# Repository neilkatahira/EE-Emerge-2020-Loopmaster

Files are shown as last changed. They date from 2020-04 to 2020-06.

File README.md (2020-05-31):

# Loop Master

[Loopmaster](https://neilkatahira.github.io/EE-Emerge-2020-Loopmaster/) is a musical project created by a team of UC Davis [EE-Emerge](https://www.ece.ucdavis.edu/ieee/home/ee-emerge/) (EEC 105ABC) students. This project allows you to create your own musical melodies or riffs, regardless of skill level or knowledge. Three custom "instruments" interface together to output notes based on the user's selections.

## Table of Contents

1. [About the Project](#about-the-project)
2. [Project Status](#project-status)
3. [Getting Started](#getting-started)
    1. [Dependencies](#dependencies)
    1. [Building](#building)
4. [How to Get Help](#how-to-get-help)
5. [Further Reading](#further-reading)
6. [Authors](#authors)
7. [Acknowledgements](#acknowledgements)

# About the Project

Three instruments (Drumpad, Computer Vision, and Footpad) work with selections specified in a MATLAB GUI. A BeagleBone Black and a Bela Cape is utilized to process user inputs and output different notes.
The Drumpad works like a traditional MIDI pad, where each of the twelve buttons are mapped to notes that relate to a selection of instruments. The Computer Vision maps different notes to select areas in a camera's view and outputs sound when a trigger is visible. The Footpad takes input from a user's feet and manipulates the sounds created by the Camera Vision and Drumpad.

# Project Status

Final assembly and code refinement.

# Getting Started

This repository can be downloaded [here](https://github.com/neilkatahira/EE-Emerge-2020-Loopmaster/archive/master.zip), or cloned by:
```
git clone https://github.com/neilkatahira/EE-Emerge-2020-Loopmaster
```

## Dependencies

#### Software
[Energia](https://energia.nu/)  
Energia is required for the Drumpad and Footpad to compile and run the .ino files.

[OpenMV IDE](https://openmv.io/pages/download)  
The OpenMV IDE is used for all of the programming of the H7 Camera.

[PureData](https://github.com/BelaPlatform/Bela/wiki/Getting-started-with-Bela)  
The Bela IDE is used for the majority of the workflow for the Beaglebone + Bela.

#### Hardware & Model Creation
[Altium](https://www.altium.com/) was used for most PCB creation.  
[Eagle](https://www.autodesk.com/products/eagle/overview) was used to make the CameraPCB.  
[Fusion 360](https://www.autodesk.com/products/fusion-360/overview) was used for the creation of enclosures and other mechanical files.  
[Cura](https://ultimaker.com/software/ultimaker-cura) was used as our main slicer for 3D printing. The UC Davis ESDC's Ultimaker's and personal Ender 3 Pro's were used for fabrication.  

## Building

PCB and enclosure files will be located in their respective subdirectories. These were fabricated either with a 3D printer, a laser cutter, or table saw.

Software for the instruments will have to be compiled and loaded into their respective MCU's either in the Puredata IDE or Energia.

# How to Get Help

You can request any changes by making a [pull request](https://github.com/neilkatahira/EE-Emerge-2020-Loopmaster/pulls) or opening an issue.

# Further Reading
* [Airdrum](https://hackaday.com/2019/11/15/finally-your-air-drumming-has-an-outlet/)
* [Foot Piano](https://www.instructables.com/id/Build-a-Big-Piano/)

# Authors

* [Benjamin Moore](https://github.com/mooreben34)
* [Conrad Rowling](https://github.com/Conrad-Rowling)
* [Neil Katahira](https://github.com/neilkatahira)
* [Jocelyn Park](https://github.com/spectivePer)
* [Isabelle Asistin](https://github.com/ijasistin)
* [Varsha Senthil](https://github.com/varshaaaaa)
* [Tyler Kelley](https://github.com/tfkelley)
* [Ryan Ma](https://github.com/RyanMa1)
* [Devon Liu](https://github.com/dvnliu)
* [Sean Alling](https://www.ece.ucdavis.edu/blog/alling-sean/)
* [Professor Andre Knoesen](https://faculty.engineering.ucdavis.edu/knoesen/)

# Acknowledgments

Thanks to Texas Instruments for sponsoring EE-Emerge, along with Sean Alling and Dr. Andre Knoesen. We would not have gotten this far without their help and support.

Huge shout out to Alessandro Verdiesen and Luuk van Kuijk with the original idea and inspiration of the [Airdrum](https://hackaday.com/2019/11/15/finally-your-air-drumming-has-an-outlet/) and the whole project.

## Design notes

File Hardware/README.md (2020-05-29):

# Hardware Designs

Our system was fairly robust, and we needed quite a few board to complete it. The backbone of our hardware was based on the following boards:

[BeagleBoneBlack](https://beagleboard.org/black)  
[Bela Cape](https://beagleboard.org/p/112305/bela-low-latency-audio-sensor-cape-for-pocketbeagle-1615e0)  
[MSP430G2 LaunchPad](http://www.ti.com/tool/MSP-EXP430G2)  
[OpenMV H7](https://openmv.io/products/openmv-cam-h7)  
Capsense Buttons
Power Supply
Batteries

Once we proved functionality, we designed our own circuitboards to improve the connections as well as size parameters of the pre-fabricated boards.

## Table of Contents

1. [Board Selection](#board-selection)  
   - [BeagleBoneBlack/BelaCape](#beagleboneblack/belaCape)  
   - [OpenMV H7](#openMv-h7)  
   - [MSP430](#msp430)  
   - [Xbee Module](#xbee-module)  
   - [Miscellaneous](#miscellaneous)  
2. [Custom Boards](#custom-boards)  
   - [Beagle Cape Cape](#beagle-cape-cape)  
   - [Drumpad/Keypad](#drumpad/keyboard)  
   - [Camera Cape](#camer-cape)  
   - [Button Wiring Harness](#button-wiring-harness)  
    
## Board Selection

### BeagleBoneBlack/BelaCape  
The base of project was creating music, which meant making quality sounds at a responsive rate. This meant we needed low latency, as low as we could get it within budget! We built our system around the [BeagleBoneBlack](https://beagleboard.org/black) and [Bela Cape](https://beagleboard.org/p/112305/bela-low-latency-audio-sensor-cape-for-pocketbeagle-1615e0) which would combined process the input of instruments and output fast and quality sound.

### OpenMV H7  
We chose the OpenMV H7 because it is a relatively cheap, low power camera, that has loads of documentation and is very easy to work with. It has more than enough processing power to accomplish our tasks, as well as an IDE that uses python. 

### MSP430  
We chose to use these boards because everyone on our team had experience working with them, they are easy to use, and use an IDE that is almost identical to the Arduino IDE. They were also provided to us in launchboard form by [Texas Instruments](http://www.ti.com/) which vastly accelerated the project developement phase. - BIG THANKS! 

### Xbee Module  
The Xbee module was a final implementation on the project to provide wireless communication. These modules are incredibly easy to use, and are very small. They are an excellent choice to provide wireless serial communication.

### Miscellaneous  
Power Supply, Batteries, Voltage Regulators and Capsense tech

## Custom Boards  
We used several Integrated Processors in the development of our project. In most cases we used development boards, jumperwires and breadboards which allowed easy connections to test functionality. We started with but the finished project was something professional, so we designed our own boards to house the integrated chips we were programming ([MSP430](http://www.ti.com/microcontrollers/msp430-ultra-low-power-mcus/overview.html)'s) as well as capes for the pre-fabricated boards we were using ([OpenMV H7](https://openmv.io/products/openmv-cam-h7) and [BeagleBoneBlack](https://beagleboard.org/black)/[Bela Cape](https://beagleboard.org/p/112305/bela-low-latency-audio-sensor-cape-for-pocketbeagle-1615e0)).This allowed us to create more stable connection points, remove unnecessary functions, and create room for new functions (Xbee wireless Communication).

### Beagle Cape Cape  
We designed a board that would connect to the breakout pins of the BeagleBoneBlack. It replaced the GPIO pinnouts with screw terminal connections for the required Serial ports and 3.3V rail. It also laid a footprint for a permanent addition of an Xbee module.

### Drumpad/Keypad  
We developed one board that would function for both the Drumpad as well as the foot keyboard. It housed a MSP430 and provided ample room for the GPIO pins that were needed in instrument function.(MORE DETAILS) THe board replaced the GPIO pin out with screw terminals for better permanent connections. The board was also made with a footprint for an Xbee module to be soldered on.

### Camera Cape  
The most simple board we designed for the OpenMV camera module, it took the pinouts we needed from the development board and implemented screw terminals for better permanent connections.

### Drumpad Wiring Harness  
We designed a board that simplified the wiring harness for 12 capacitive sense buttons. Each button required an op-amp to forward the button data as well as provide power to LEDs. We developed a board that made this complex wiring array compact and easy to trouble shoot. This allowed us to reduce the overall size requirements of the Drumpad Enclosure as well as reducing EM noise within the enclosure.

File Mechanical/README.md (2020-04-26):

# Hub
We designed a centralized hub to house everything from a powersupply to our finished boards. Changes had to be made from laser cutting to 3D printing, so the model had to be broken up into printable pieces.

# Camera
To mount the OpenMV H7 camera we used a STL file provided by OpenMV [here](https://openmv.io/collections/products/products/openmv-cam-h7-case) and modified it into a vertical mount with a ball and socket adjustment.

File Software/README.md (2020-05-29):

# Software  
Multiple Programming Languages and Development environments were used to design instrument logic as well as handle audio processing.

## Pure Data  
Pure Data is an open source programming language with a focus on multimedia applications. It was used for the Loopmaster's core audio backend since Pure Data has core native support on the Bela Cape Board. More information about the project's main .pd module and its abstractions can be found in its subdirectory.

## Camera  
The camera code is written in python using the OpenMV IDE. Its used for object detection and tracking, specifically looking for an LED in a grayscale image and pinging when that LED enters regions we've determined to output notes.

## GUI  
The GUI was created with MATLAB's App Designer. It utilizes UART to send data to an Arduino Uno, which then is sent and processed by the Beaglebone + Bela with the help of PureData.

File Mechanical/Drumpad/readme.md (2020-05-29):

# Drumpad  
The entire enclosure is 3D printed using an Ender 3 Pro using PLA using 0.2mm layer height. To improve printing time, a larger layer height with a larger nozzle will help.  

## Assembly  
Drumpad Base + Walls.stl and Drumpad Top.stl go together to make a single box. Inside are standoffs for the Drumpad LED pcb, and space for the actual brains of the instrument. Sensor Enclosure.stl is a model of for a Capsense sensor, just in case you want to adapt it to another design. Drumpad PCB plate .stl is a simple plate that screws underneath the Drumpad LED pcb with M3 screws and nuts if not using the original enclosure.

## Notes  
Supports for a hole in the Drumpad Base + Walls.stl may or may not be required depending on the capabilities of your printing solution. Print with a brim if issues such as corners warping occur. Scaling may break how everything comes together, so if your print bed is not big enough, slice in half and put together with superglue or by other means.

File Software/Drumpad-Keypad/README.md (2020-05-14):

# Drumpad/Keypad Code
The code for the drumpad/keypad was developed in the energia IDE and is fairly straightforward: It polls the GPIO pins for a change of state, either being pressed or released. The code reads the status of each pin and compares it to a flag that describes the state it was previously in. When pressed a PRESS flag is set, and is not removed until the digital value of the pin falls below the boolean value of the flag. Then the process is repeated. Each pin sends a unique 8 bit char to through UART to the bela telling it which key was pressed/released.

# Keypad Code
The Keyboard code is written in C and programmed on the MSP430. Each of the keys is connected to a different pin on the MSP430. When a key is pressed, the two boards with copper tape make contact with each other, and the corresponding pin on the MSP is read, and an output is sent through UART as a single character. We programmed each key to output a different character to identify which key was being pressed. This is looped continuously and the Bela reads the characters sent to output the corresponding sounds.

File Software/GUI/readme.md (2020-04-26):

## MATLAB GUI
Found in the MATLAB folder is a MATLAB App Designer GUI with an exported .m file for full modification.

## Arduino
In the Arduino folder, there resides a file for taking serial data from MATLAB, parsing and sending with UART. There is also a second optional Arduino file for sniffing what is sent with MATLAB.

## Setup
1. Connect Arduino to computer by USB.
2. Connect Arduino TX -> Beaglebone BELA RX. Alternatively, connect to another Arduino UNO with TEST_serialReceive.ino. Connect to ground to establish physical UART.
    * If using second Arduino UNO, load code in TEST_serialReceive.ino with GND disconnected. Then, reconnect GND.
3. Open UART_GUI.ino in Arduino IDE. Check COM ports and upload to board.
4. Open LoopMasterApp.mlapp. Check COM port and baudrate in line 45. Change accordingly and run. Make sure connections are secure and data is sent/received.

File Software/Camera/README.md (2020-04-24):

# OpenMV Code
The software for tracking our camera instrument was developed in OpenMVide. This was a really straightforward IDE with tons of community activity. It had plenty of options to improve the code using computer learning algorithms and object identification. We tested a variety of different ways to track an object and found that using simple algorithms lead to in accurate readings, and using complex algorithms - TensorFLow or other computer training- to identify and track an object created too much of a delay. From those preliminary tests, we decided to simplify the object instead. We tracked an LED in grayscale and searched for areas in which the pixel value was white < [253]. To do this we used an algorithm provided in the openmv micropython libray call findblobs() you pass it threshold values to define what kind of blob and the size requirements. It will find all the blobs that meet that criteria, then we searched through those blobs to see if the center of any of those blobs fit inside certain areas of the screen (each corner). If a blob is in a corner we send the bela a code to play a note designated by that corner.

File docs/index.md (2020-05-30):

# LoopMaster

[LoopMaster](https://neilkatahira.github.io/EE-Emerge-2020-Loopmaster/) is a musical project created by a team of UC Davis [EE-Emerge](https://www.ece.ucdavis.edu/ieee/home/ee-emerge/) (EEC 105ABC) students. This project allows you to create your own musical melodies or riffs, regardless of skill level or knowledge. Three custom "instruments" interface together to output notes, chords, and audio manipulations based on the user's selections.  

{%include youtubePlayer.html id="1H5Hb9ecIn0"%}  

# About the Project:
The goal of this project was to create a functional music creation tool, and demonstrate various input methods. We wanted to make something that was easy for beginners to pick up and make something that sounds nice, but also create an enjoyable experience for someone more serious.<br/>

However there are many factors that can detract from musical creation, particulary poor sound quality and latency. To ensure that the music we were making was responsive and sounded good, we designed our project around the [Bela](https://shop.bela.io/products/bela-starter-kit):

{%include youtubePlayer.html id="Os2ljj1cIog"%}

We used it in conjunction with a [BeagleBone Black](https://beagleboard.org/black) to process incoming signals, and respond with fast - quality sound. <br/>

The next step was creating a way to get user input; we thought of a couple very creative was to use technologies like [Capsense Buttons](https://en.wikipedia.org/wiki/Capacitive_sensing) and an easy to use [Computer Vision Module](https://openmv.io/). We built our own Circuit Boards to house MicroControllers that would process our user input, and convert it to UART. We chose the [MSP430G2553](https://www.ti.com/product/MSP430G2553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) for our microcontroller because [TI](https://www.ti.com/) sponsored our course, and the associated [Launchpad](http://www.ti.com/tool/MSP-EXP430G2) drastically increased our software development time. <br/>

Then we decided to take the project wireless! using a straightforward network of [XBee](https://www.adafruit.com/product/964) modules we were able to send multiple UART messages in unison, and create a modular sleek look to the system.

Our final signal flow chart ended up like this:

<p align="center">
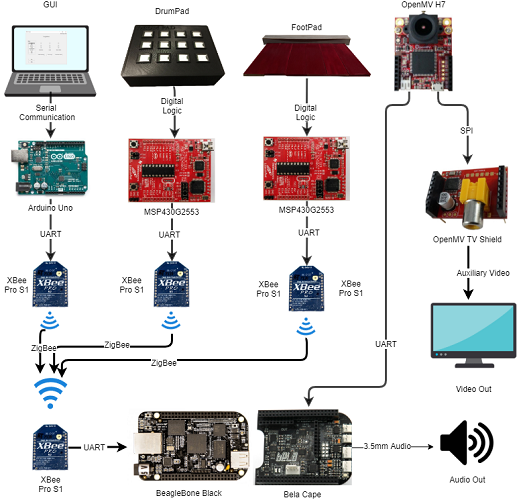
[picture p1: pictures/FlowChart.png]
  
</p>

<video>

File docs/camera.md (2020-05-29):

# Camera

## Hardware  
We chose the OpenMV H7 because it is an affordable, low power camera that is well documented and easy to work with. It has more than enough processing power to accomplish our tasks, as well as an integrated Python based IDE. Using Python allowed us to take advantage of open source libraries, which simplified the learning curve of image processing algorithms.

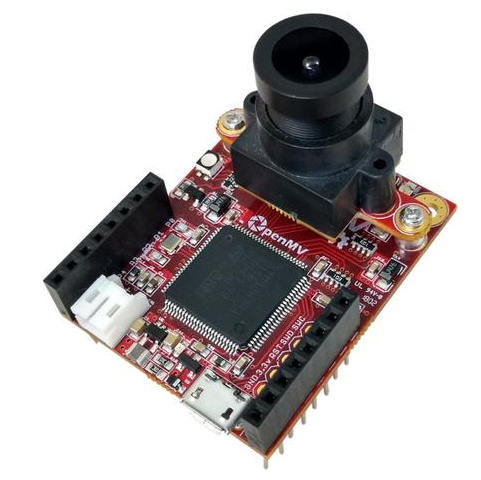
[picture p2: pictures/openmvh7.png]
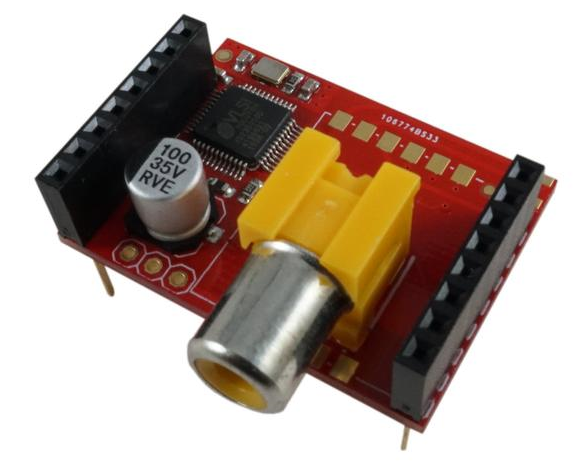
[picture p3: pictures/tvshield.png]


## Mechanical  
To mount the OpenMV H7 camera, we used a STL file provided by OpenMV [here](https://openmv.io/collections/products/products/openmv-cam-h7-case) and modified it in order to fit a [TV shield](https://openmv.io/collections/products/products/tv-shield) as well as screw terminals. To play the "camera instrument" live video feed is necessary to provide the user with the camera's field of view. A vertical mount was also added taking advantage of a ball socket, for a full range of adjustment. This mount was then superglued onto the main Hub of the project.  
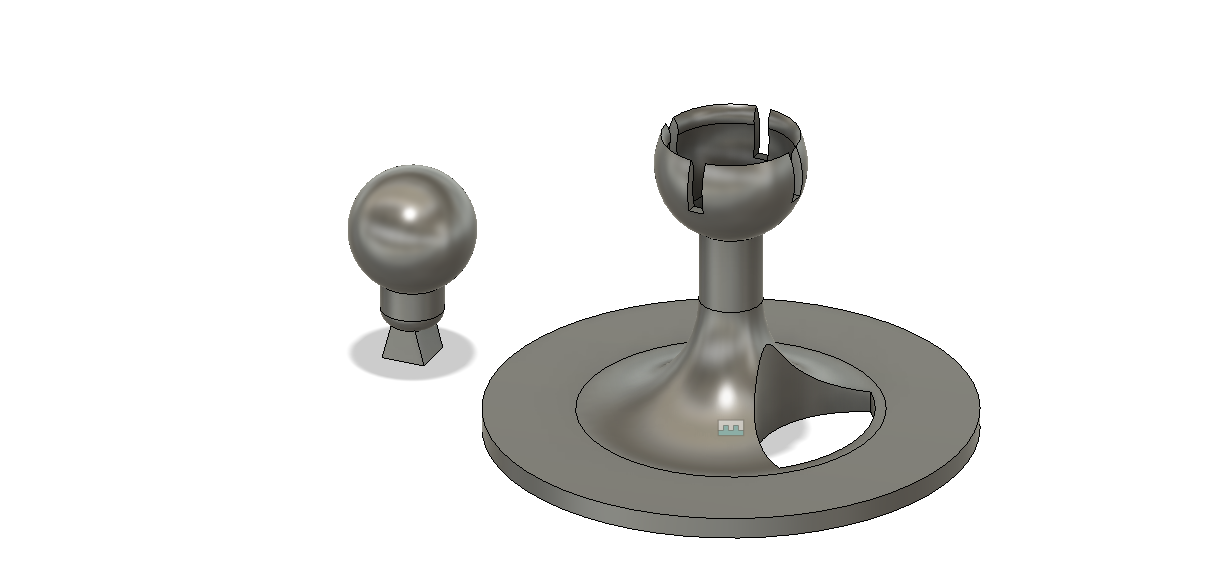
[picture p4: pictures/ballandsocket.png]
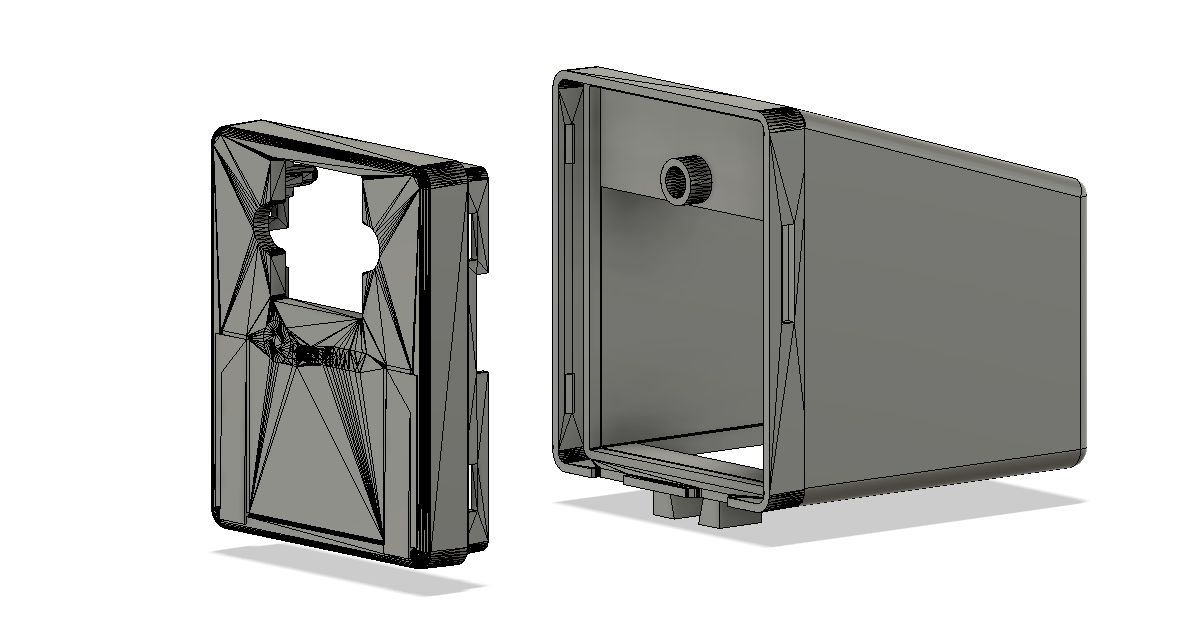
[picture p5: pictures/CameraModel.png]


## Software  
The software for tracking our camera instrument was developed in the OpenMV IDE. This is a straightforward IDE with an extensive user base. It had plenty of options to improve the code using computer learning algorithms and object identification.

<p align="center">
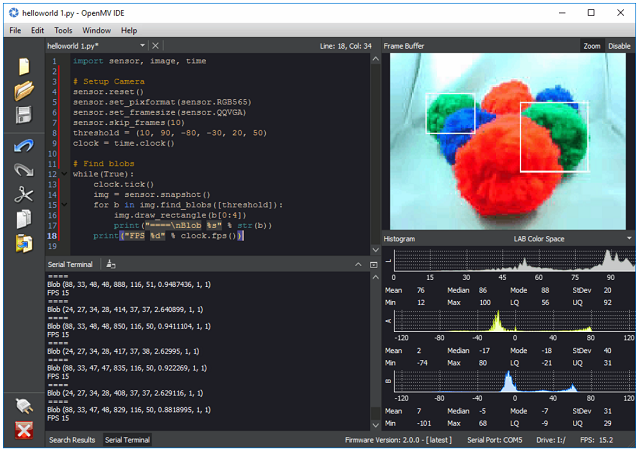
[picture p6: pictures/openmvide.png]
  
</p>

We tested a variety of different ways to track an object and found that using simple algorithms lead to inaccurate readings, and using complex algorithms - TensorFlow or other computer training - to identify and track an object created too much of a delay. From those preliminary tests, we decided to simplify the object instead.  
We tracked an LED in grayscale and searched for areas in which the pixel value was white < [253]. To do this we used an algorithm provided in the OpenMV Micropython library called  findblobs(). Threshold values are passed to define what kind of blob should be detected. Given this, it will find all the blobs that meet that criteria. Then, we searched through those blobs to see if the center of any of those blobs fit inside certain areas of the screen (each corner). If a blob is in a corner, we send the BeagleBone + Bela a code to play a note designated by that corner.

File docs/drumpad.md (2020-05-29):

# Drum Pad  
 The Drum Pad is a MIDI Pad-like instrument that houses twelve capacitive touch sensors.  These sensors are all mapped towards different sounds that are programmed within Pure Data code. When styles are changed within the GUI, the sensors will output their corresponding sounds. 

## Hardware  
Hardware that is used in the Drum Pad include two custom PCB's: one that implements a comparator circuit with LM741 OP-Amps to facilitate sensor presses, and one that houses a MSP430 and an XBee module for wireless serial communication to the BeagleBone + Bela. The latter PCB is also used with the FootPad instrument.  

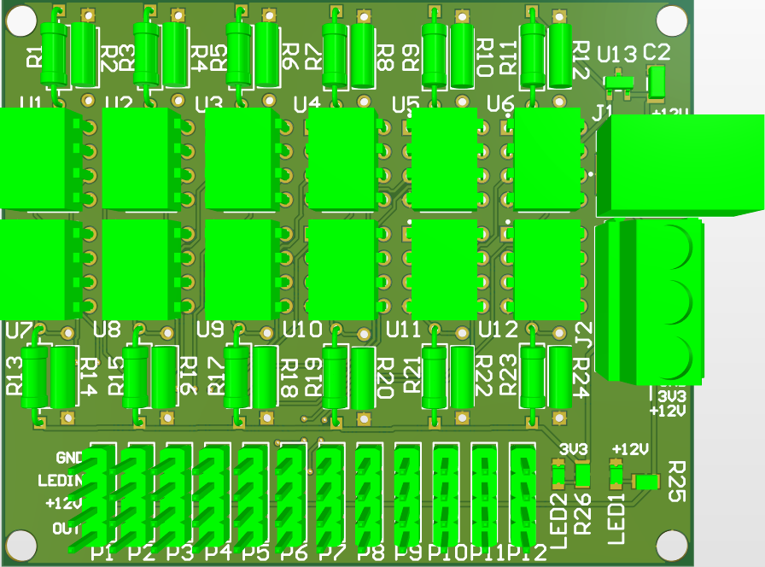
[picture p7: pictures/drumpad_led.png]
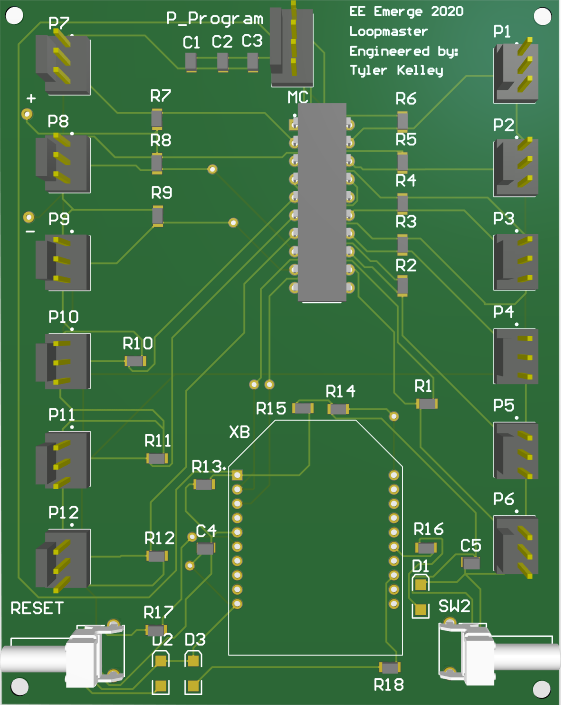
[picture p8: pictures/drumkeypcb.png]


## Mechanical  
The entire enclosure is 3D printed using an Ender 3 Pro using PLA with 0.2mm layer height. To improve printing time, a larger layer height with a larger nozzle will help.

Drumpad Enclosure  

#### Assembly  
Drumpad Base + Walls.stl and Drumpad Top.stl go together to make a single box. Inside are standoffs for the Drumpad LED pcb, and space for the actual brains of the instrument. Sensor Enclosure.stl is a model of for a Capsense sensor, just in case you want to adapt it to another design. Drumpad PCB plate .stl is a simple plate that screws underneath the Drumpad LED pcb with M3 screws and nuts if not using the original enclosure.

#### Notes  
Supports for a hole in the Drumpad Base + Walls.stl may or may not be required depending on the capabilities of your printing solution. Print with a brim if issues such as corners warping occur. Scaling may break how everything comes together, so if your print bed is not big enough, slice in half and put together with superglue or by other means.

## Software  
Software used for the Drum Pad is created using CCS Cloud / Energia and is loaded onto a MSP430.

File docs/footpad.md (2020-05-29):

# FootPad  
The FootPad is a large six input floor board where inputs are passed with a user's feet. The FoodPad manipulates the sounds created by the Camera Vision and Drumpad.

## Hardware
The FootPad uses the same main XBee PCB as the DrumPad. Each board press is detected as separate lines with UART.  

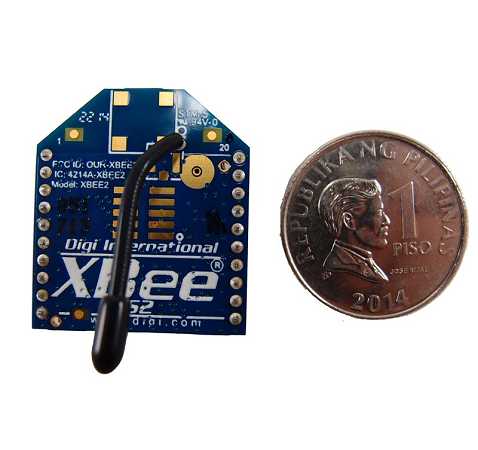
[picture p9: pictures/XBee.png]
   

## Mechanical  
The FootPad was created using 1/4" Plywood, 1/2" foam, copper tape, and screws. For each input, we wrapped one 4" x 1" x 1/4" Plywood pieces with copper tape and a 3" strip down the middle of two 6" x 24" x 1/4" Plywood pieces. The two pieces of plywood are then screwed together separated by 1/2" foam to prevent the copper tape from touching each other, creating a basic switch.

 

## Software  
Software used for the FootPad was created using CCS Cloud / Energia and was loaded onto a MSP430.  It is the same as code used in the DrumPad.

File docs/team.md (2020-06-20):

# Team

| | |
|:---:|:---:|
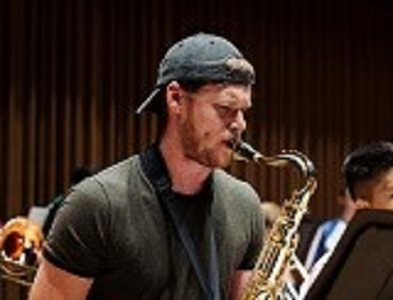
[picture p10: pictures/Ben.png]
Ben
|**Benjamin Moore** <br/> **Team Leader** <br/> B.S. Electrical Engineering June 2021 <br/> Focus: Audio DSP Engineer <br/> [LinkedIn](https://linkedIn.com/in/brmoore21) & [GitHub](https://github.com/mooreben34) |  |
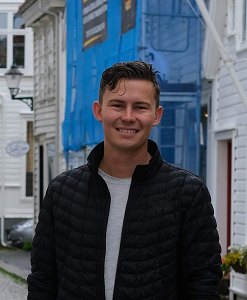
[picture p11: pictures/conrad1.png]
Conrad
|**Conrad Rowling** <br/> **Team Leader** <br/> B.S. Electrical Engineering June 2021 <br/> [LinkedIn](https://www.linkedin.com/in/conrad-rowling-28b569196/) & [GitHub](https://github.com/Conrad-Rowling) |  |
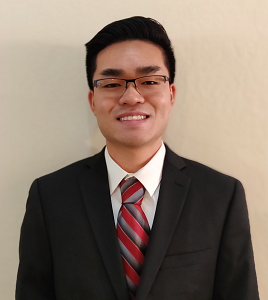
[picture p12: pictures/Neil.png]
Neil
|**Neil Katahira** <br/> B.S. Computer Engineering June 2021 <br/> Aspiring SoC / Hardware Engineer <br/> [LinkedIn](https://linkedIn.com/in/neilkatahira) & [GitHub](https://github.com/neilkatahira) |  |
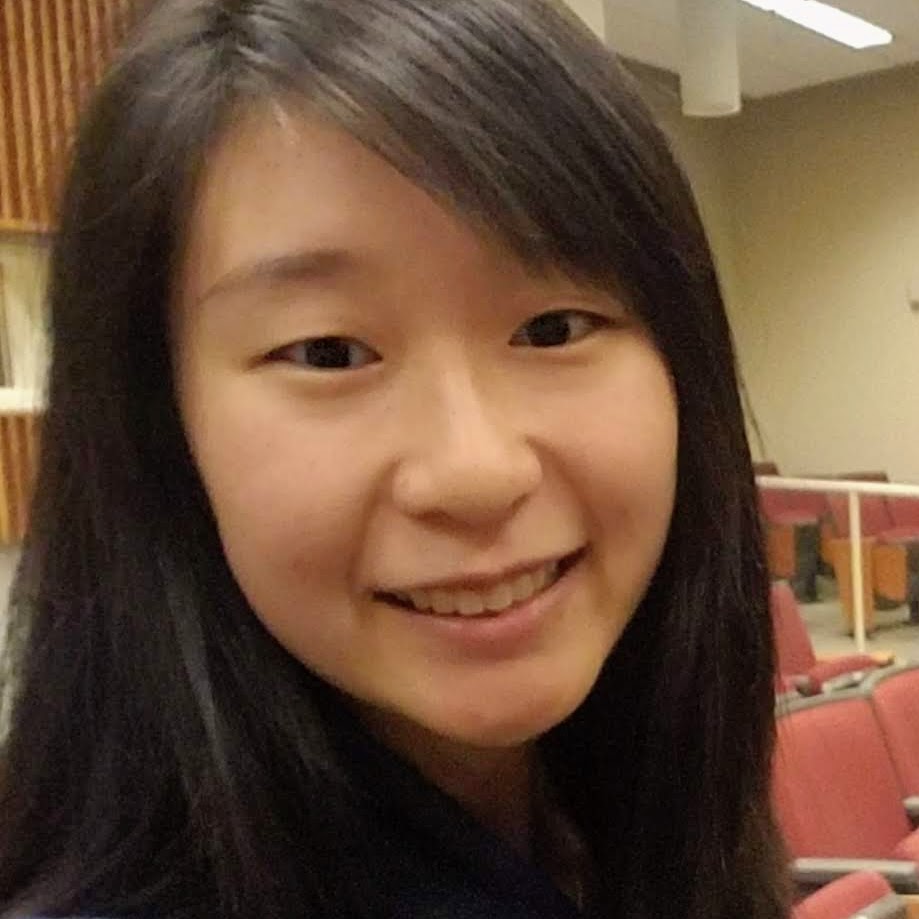
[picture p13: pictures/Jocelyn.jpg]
|**Jocelyn Park** <br/> B.S. Electrical & Computer Engineering <br/> December 2021 <br/> Aspiring DSP Engineer <br/> [LinkedIn](https://linkedIn.com/in/jocelyn-park) & [GitHub](https://github.com/spectivePer) ||
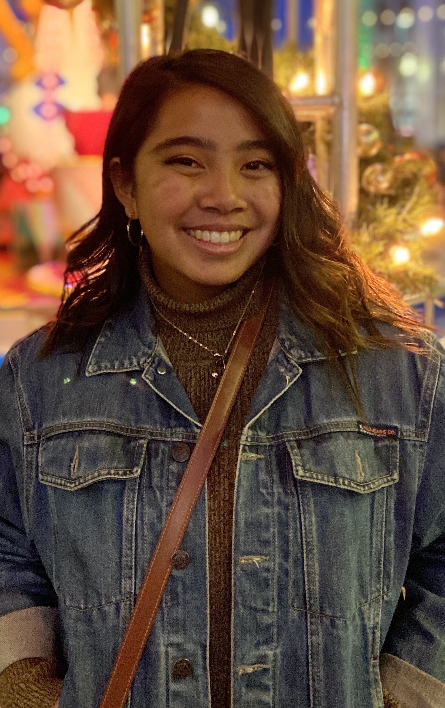
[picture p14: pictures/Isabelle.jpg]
|**Isabelle Asistin** <br/> B.S. Electrical Engineering June 2021 <br/> [LinkedIn](https://linkedIn.com/in/isabelle-asistin) & [GitHub](https://github.com/ijasistin) |  |
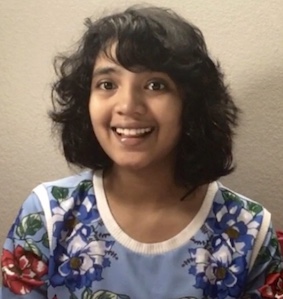
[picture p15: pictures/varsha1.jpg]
|**Varsha Senthil** <br/> B.S. Computer Engineering June 2022 <br/> Aspiring Hardware Engineer <br/> [LinkedIn](https://linkedIn.com/in/varshasenthil) & [GitHub](https://github.com/varshaaaaa) |  |
|**Tyler Kelley** <br/> B.S. Electrical Engineering June 2021 <br/> Focus: Electromagnetics <br/> [LinkedIn](https://www.linkedin.com/in/tyler-f-kelley/) & [GitHub](https://github.com/tfkelley) | |
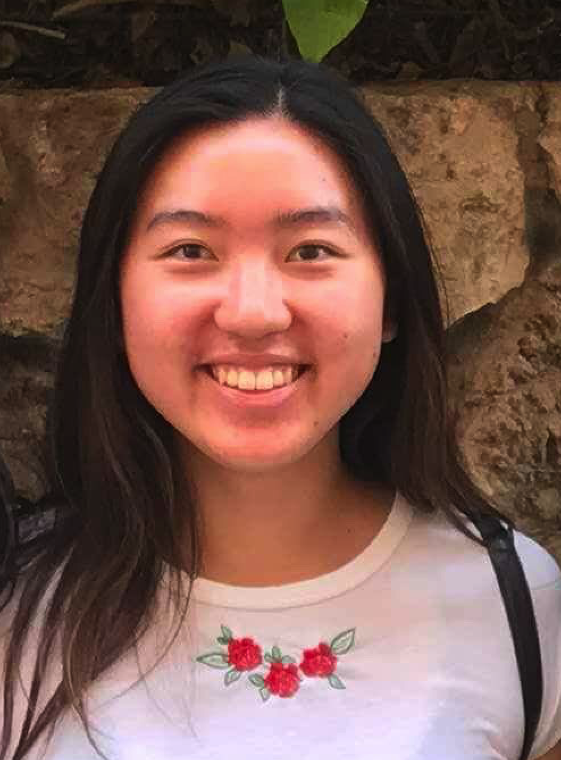
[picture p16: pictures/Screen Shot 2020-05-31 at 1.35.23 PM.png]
|**Devon Liu** <br/> B.S. Electrical Engineering June 2022 <br/> [LinkedIn](www.linkedin.com/in/devon-liu-695736119) & [GitHub](https://github.com/dvnliu) ||

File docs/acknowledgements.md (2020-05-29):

## Acknowledgements
Thank you to Texas Instruments for sponsoring EE-Emerge.  

Thank you Ryan Ma for your contributions on the Camera instrument during Winter Quarter 2020.

Special thanks to Sean Alling and Dr. Andre Knoesen. We would not have gotten this far without their help and support.  

Huge shout out to Alessandro Verdiesen and Luuk van Kuijk with the original idea and inspiration of the Airdrum and the whole project.

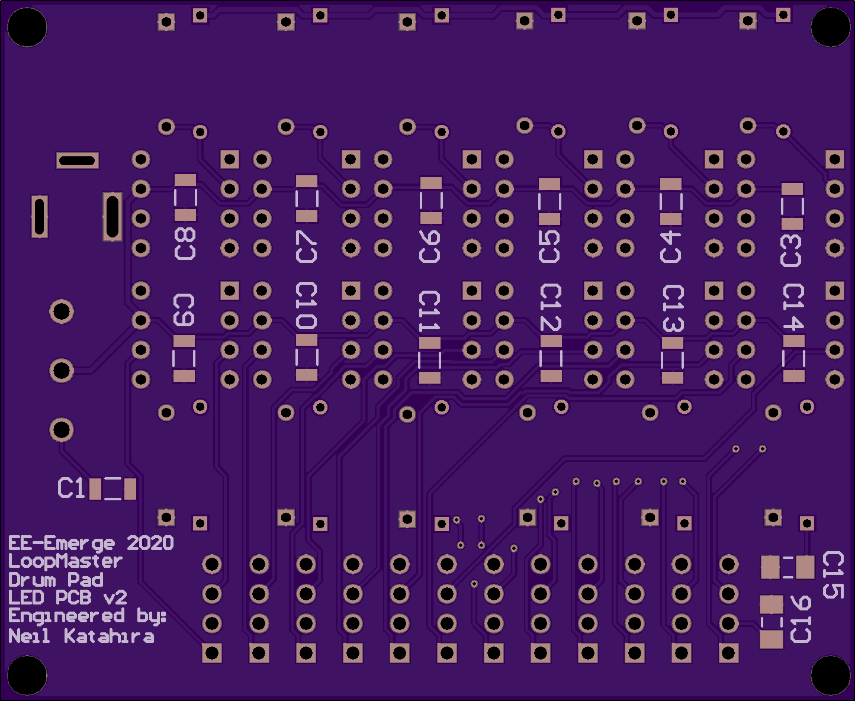
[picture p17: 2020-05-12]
Hardware/Drumpad/LEDPCB v2/back.png

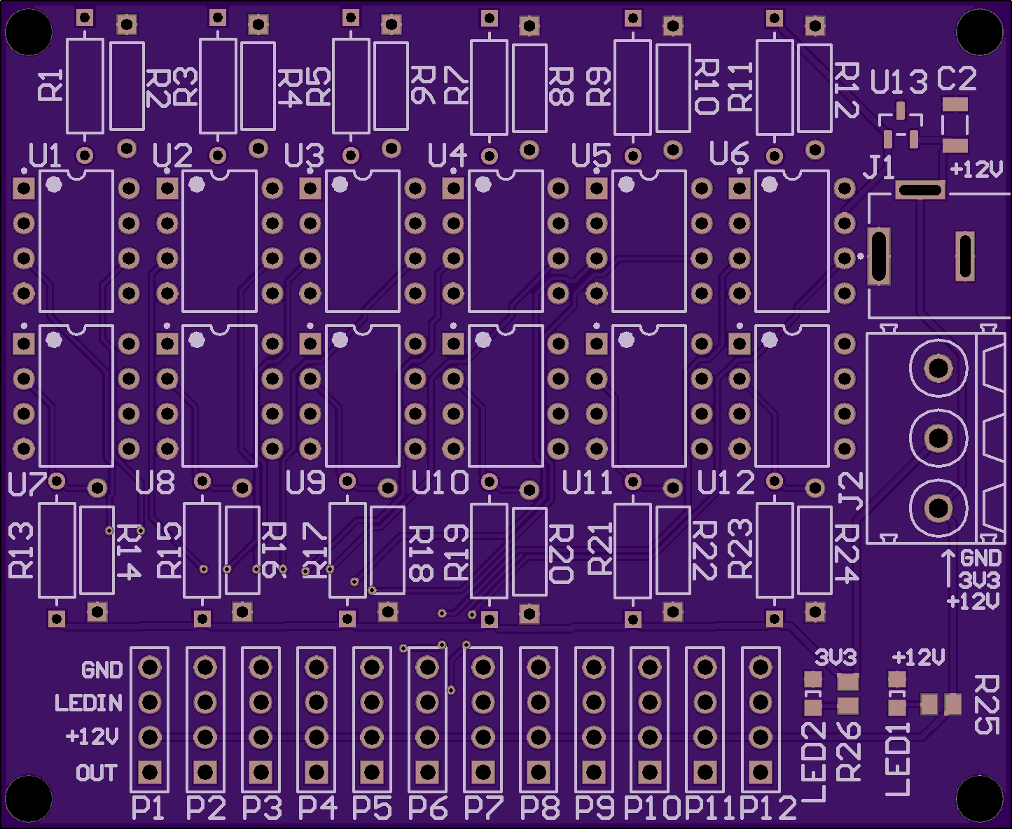
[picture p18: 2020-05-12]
Hardware/Drumpad/LEDPCB v2/front.png

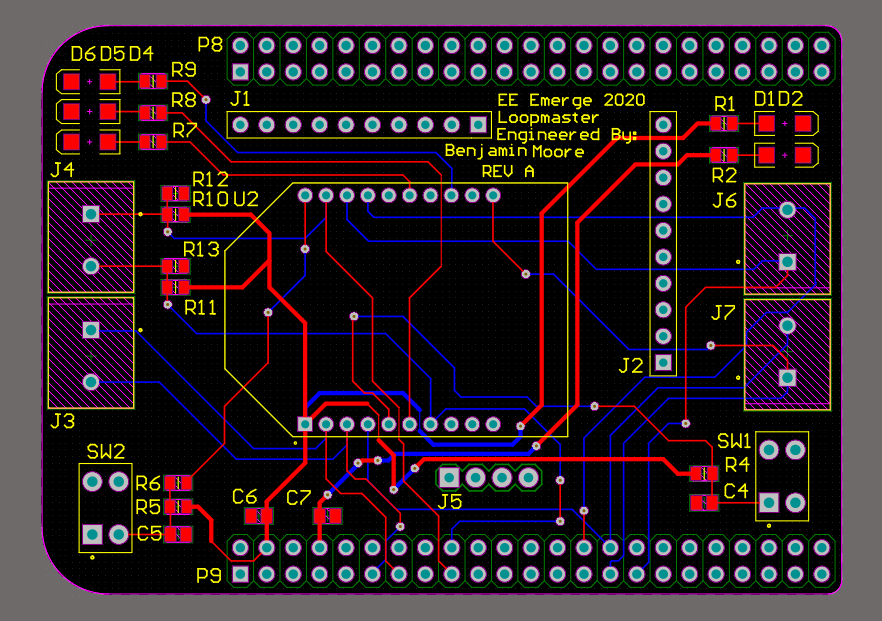
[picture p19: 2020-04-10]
Hardware/Bela_Cape_Expansion/bela_expansion_card.PNG

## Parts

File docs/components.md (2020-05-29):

# Components  
Three in-house built instruments (DrumPad, Camera, and FootPad) work with selections specified in a MATLAB GUI communicating with a BeagleBone Black and Bela Capa.  The BeagleBone Black and Bela Cape is utilized to process user inputs and output different notes or chords.

## DrumPad
The Drumpad works like a traditional MIDI pad, where each of the twelve buttons are mapped to notes that relate to a selection of instruments.  

Drumpad  

## Camera
The Camera uses computer vision to map different notes to select areas in a camera's view and tracks an LED to trigger sound.  

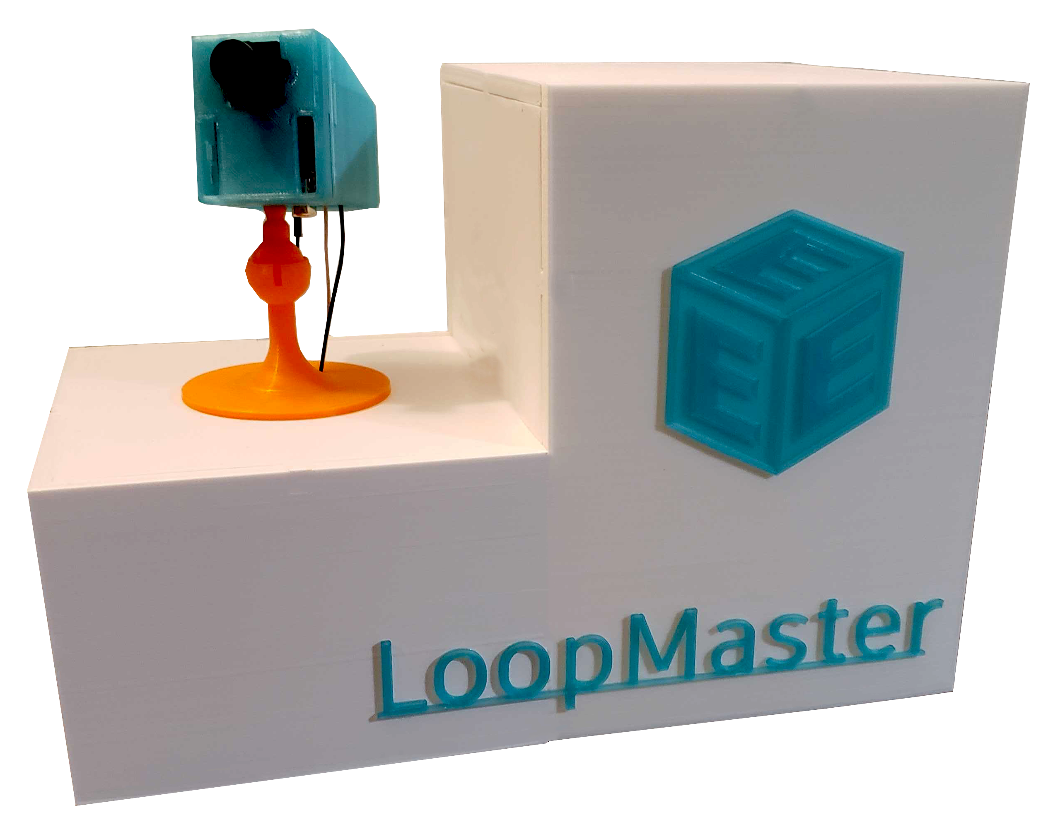
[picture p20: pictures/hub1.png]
Camera
  

## FootPad
The FootPad takes input from a user's feet and manipulates the sounds created by the Camera Vision and Drumpad.  

Footpad

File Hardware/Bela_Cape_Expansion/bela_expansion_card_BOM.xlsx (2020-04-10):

Index | Quantity | Part Number | Manufacturer Part Number | Description | Customer Reference | Available | Backorder | Unit Price | Extended Price USD
1 | 1 | 311-1472-1-ND | CC0805KRX7R0BB102 | CAP CER 1000PF 100V X7R 0805 |  | 1 | 0 | 0.13 | 0.13
2 | 3 | 399-1177-1-ND | C0805C104Z5VACTU | CAP CER 0.1UF 50V Y5V 0805 |  | 3 | 0 | 0.1 | 0.30
3 | 4 | A98076-ND | 282836-2 | TERM BLK 2POS SIDE ENTRY 5MM PCB |  | 4 | 0 | 0.71 | 2.84
4 | 2 | A126365CT-ND | CRG0805F390R | RES SMD 390 OHM 1% 1/8W 0805 |  | 2 | 0 | 0.1 | 0.20
5 | 1 | A130144CT-ND | CRGCQ0805J47K | CRGCQ 0805 47K 5% |  | 1 | 0 | 0.1 | 0.10
6 | 2 | 311-4.70KCRCT-ND | RC0805FR-074K7L | RES SMD 4.7K OHM 1% 1/8W 0805 |  | 2 | 0 | 0.1 | 0.20
7 | 2 | 311-0.0ARCT-ND | RC0805JR-070RL | RES SMD 0 OHM JUMPER 1/8W 0805 |  | 2 | 0 | 0.1 | 0.20
8 | 1 | 754-1169-1-ND | APTR3216PBC/A | LED BLUE CLEAR CHIP SMD |  | 1 | 0 | 0.59 | 0.59
9 | 2 | 160-1167-1-ND | LTST-C150CKT | LED RED CLEAR 1206 SMD |  | 2 | 0 | 0.34 | 0.68
10 | 1 | 160-1169-1-ND | LTST-C150GKT | LED GREEN CLEAR 1206 SMD |  | 1 | 0 | 0.31 | 0.31
11 | 10 | 311-1.0KARCT-ND | RC0805JR-071KL | RES SMD 1K OHM 5% 1/8W 0805 |  | 10 | 0 | 0.035 | 0.35
12 | 2 | 450-1650-ND | 1825910-6 | SWITCH TACTILE SPST-NO 0.05A 24V |  | 2 | 0 | 0.1 | 0.20
DIGIKEY LINK
https://www.digikey.com/short/zp444q

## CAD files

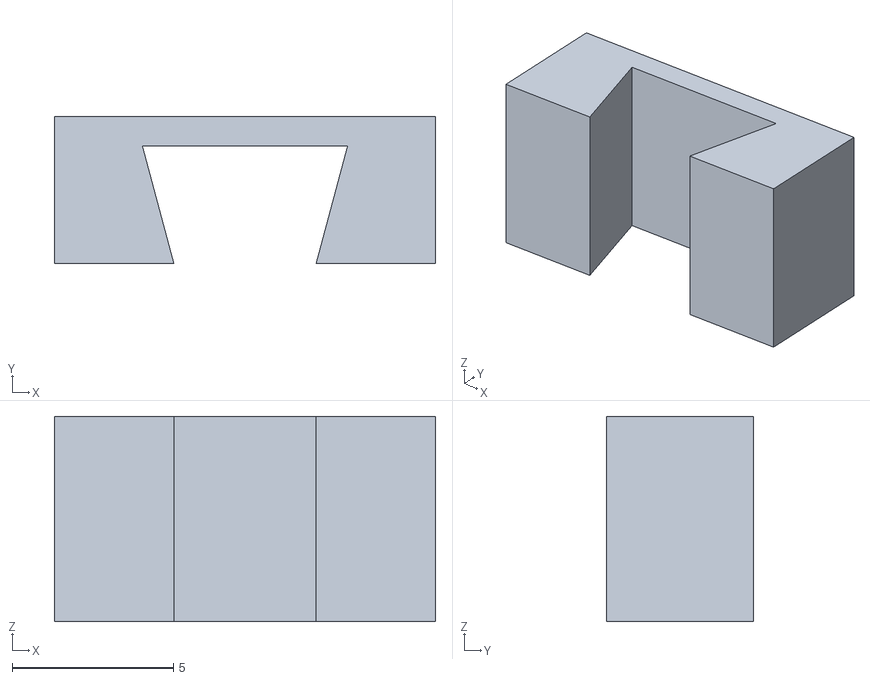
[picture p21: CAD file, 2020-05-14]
Mechanical/Camera Mount/Fitting.stl
11.8 x 4.55 x 6.36

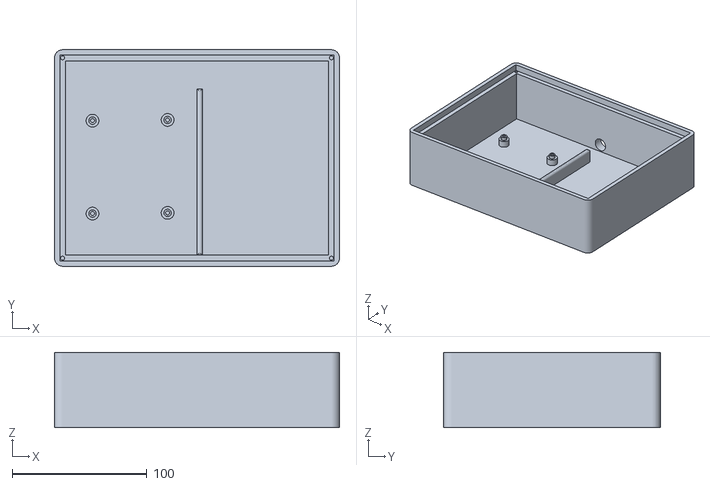
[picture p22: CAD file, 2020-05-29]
Mechanical/Drumpad/Drumpad Base + Walls.stl
211.5 x 160.7 x 56.0

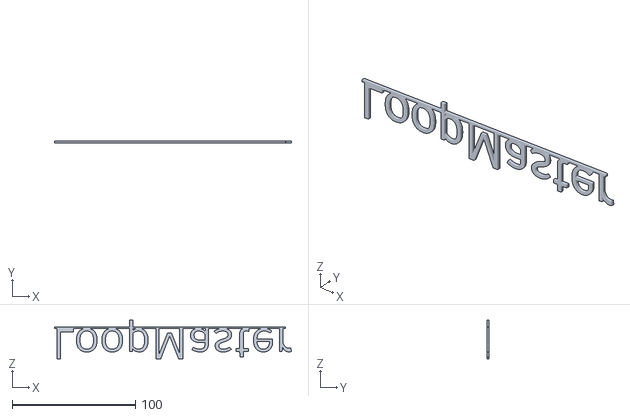
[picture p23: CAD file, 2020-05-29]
Mechanical/Hub/Name v2.stl
192.4 x 2.00 x 31.5

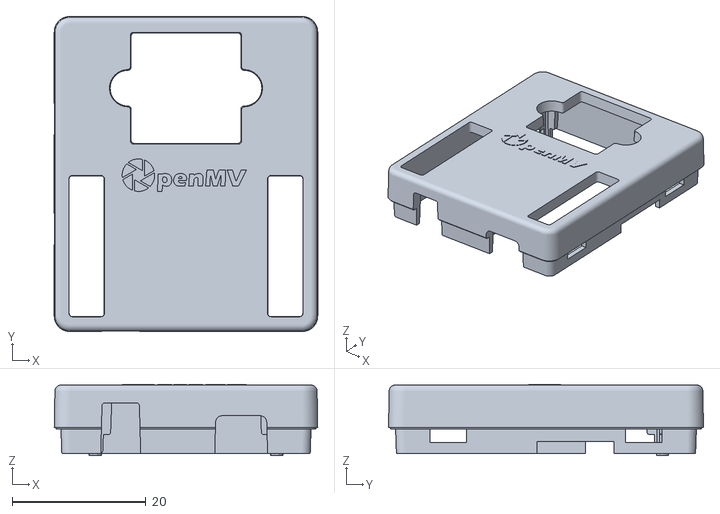
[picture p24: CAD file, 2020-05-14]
Mechanical/Camera Mount/CaseTop.stl
39.5 x 47.2 x 10.6

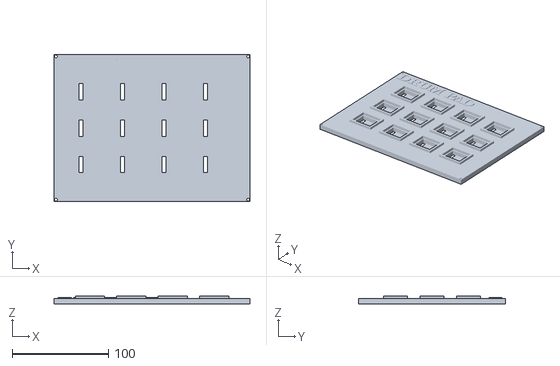
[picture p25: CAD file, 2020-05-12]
Mechanical/Drumpad/Drumpad Top.stl
203.3 x 152.5 x 8.77

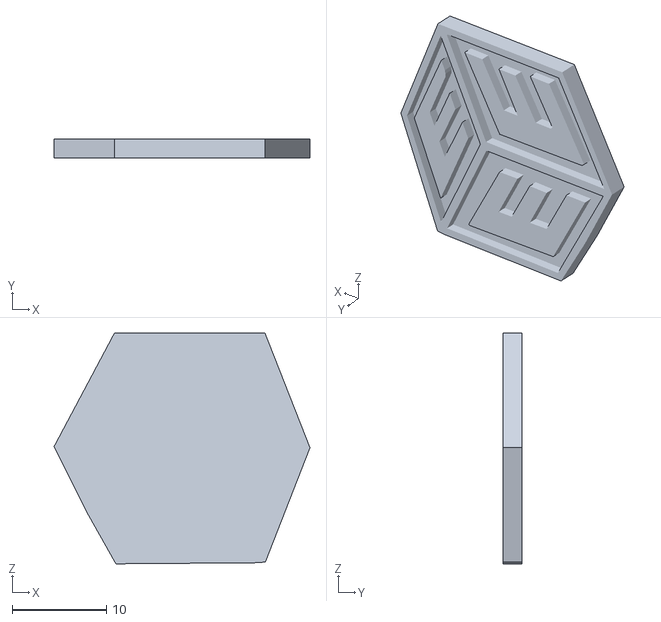
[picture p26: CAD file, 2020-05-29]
Mechanical/Hub/Logo.stl
27.2 x 2.00 x 24.5

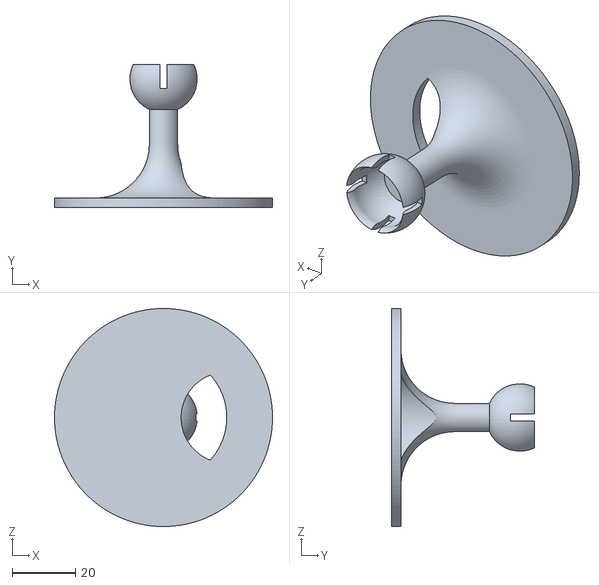
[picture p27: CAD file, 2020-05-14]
Mechanical/Camera Mount/CameraMount.stl
69.0 x 45.2 x 69.0

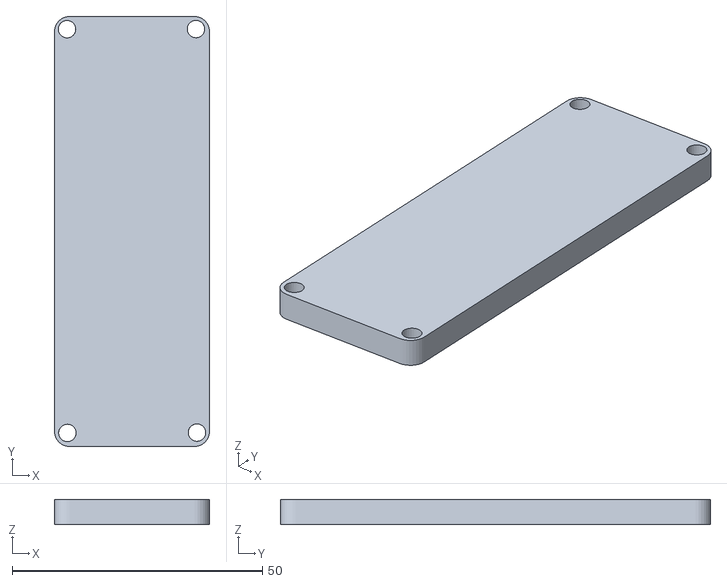
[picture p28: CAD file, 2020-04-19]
Mechanical/Drumpad/drumpad pcb plate v2.stl
31.0 x 86.0 x 5.00

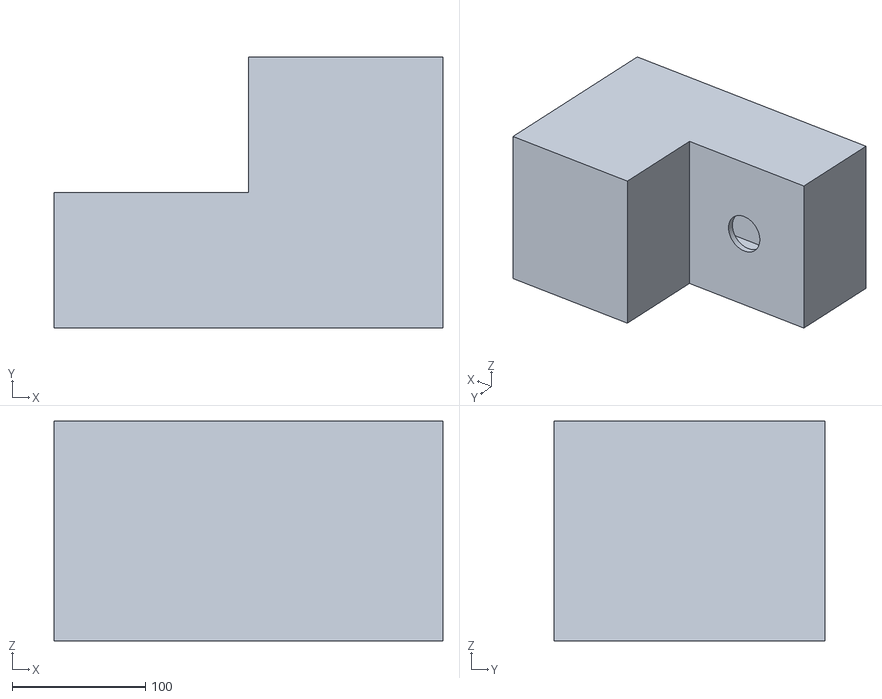
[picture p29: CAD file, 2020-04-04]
Mechanical/Hub/Hub v6.stl
292.1 x 203.2 x 165.1

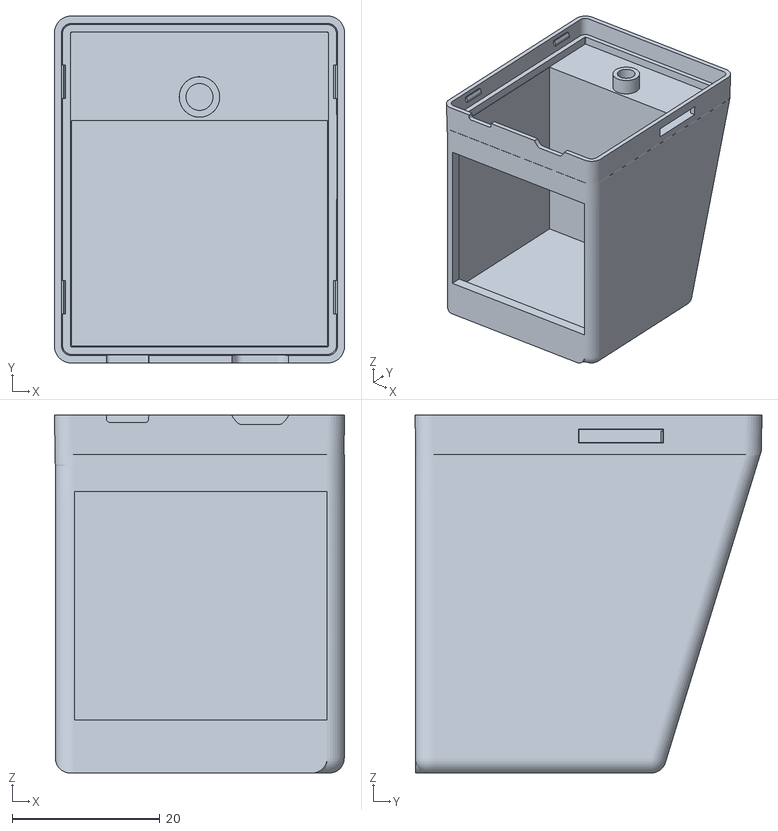
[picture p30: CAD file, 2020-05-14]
Mechanical/Camera Mount/CaseBack.stl
39.2 x 46.9 x 48.4

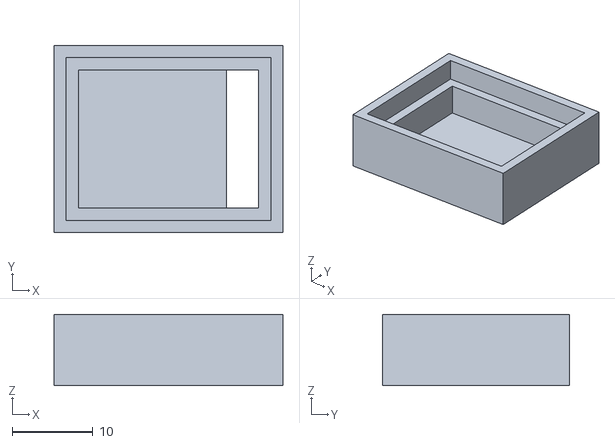
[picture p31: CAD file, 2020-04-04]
Mechanical/Drumpad/Sensor Enclosure v15.stl
28.3 x 23.1 x 8.77

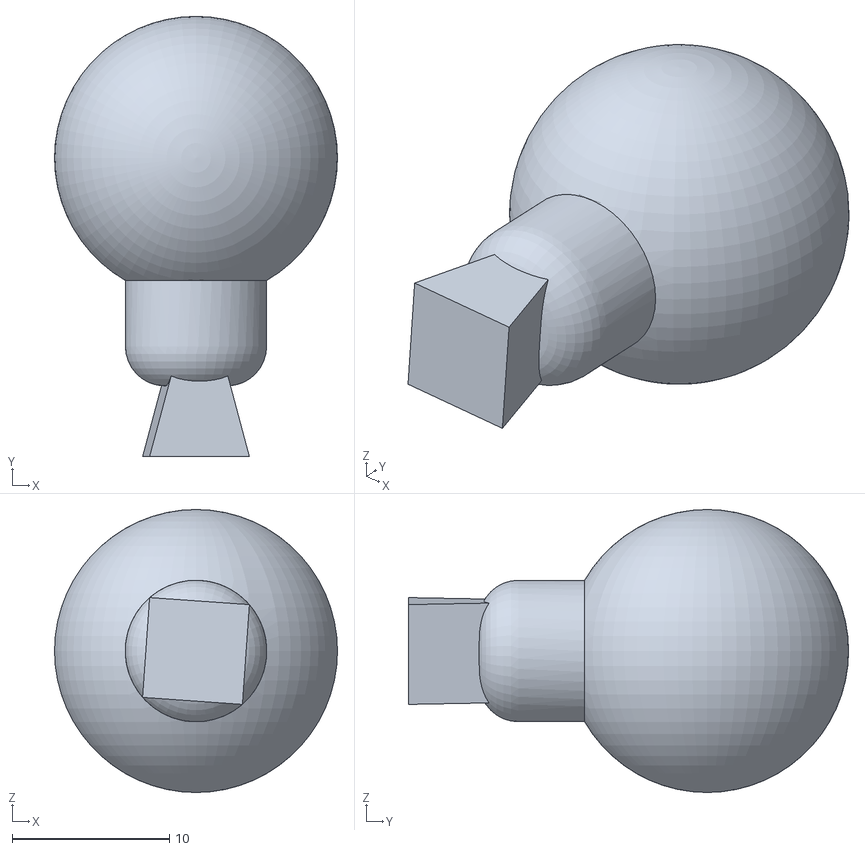
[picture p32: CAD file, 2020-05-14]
Mechanical/Camera Mount/ball.stl
18.0 x 28.0 x 18.0

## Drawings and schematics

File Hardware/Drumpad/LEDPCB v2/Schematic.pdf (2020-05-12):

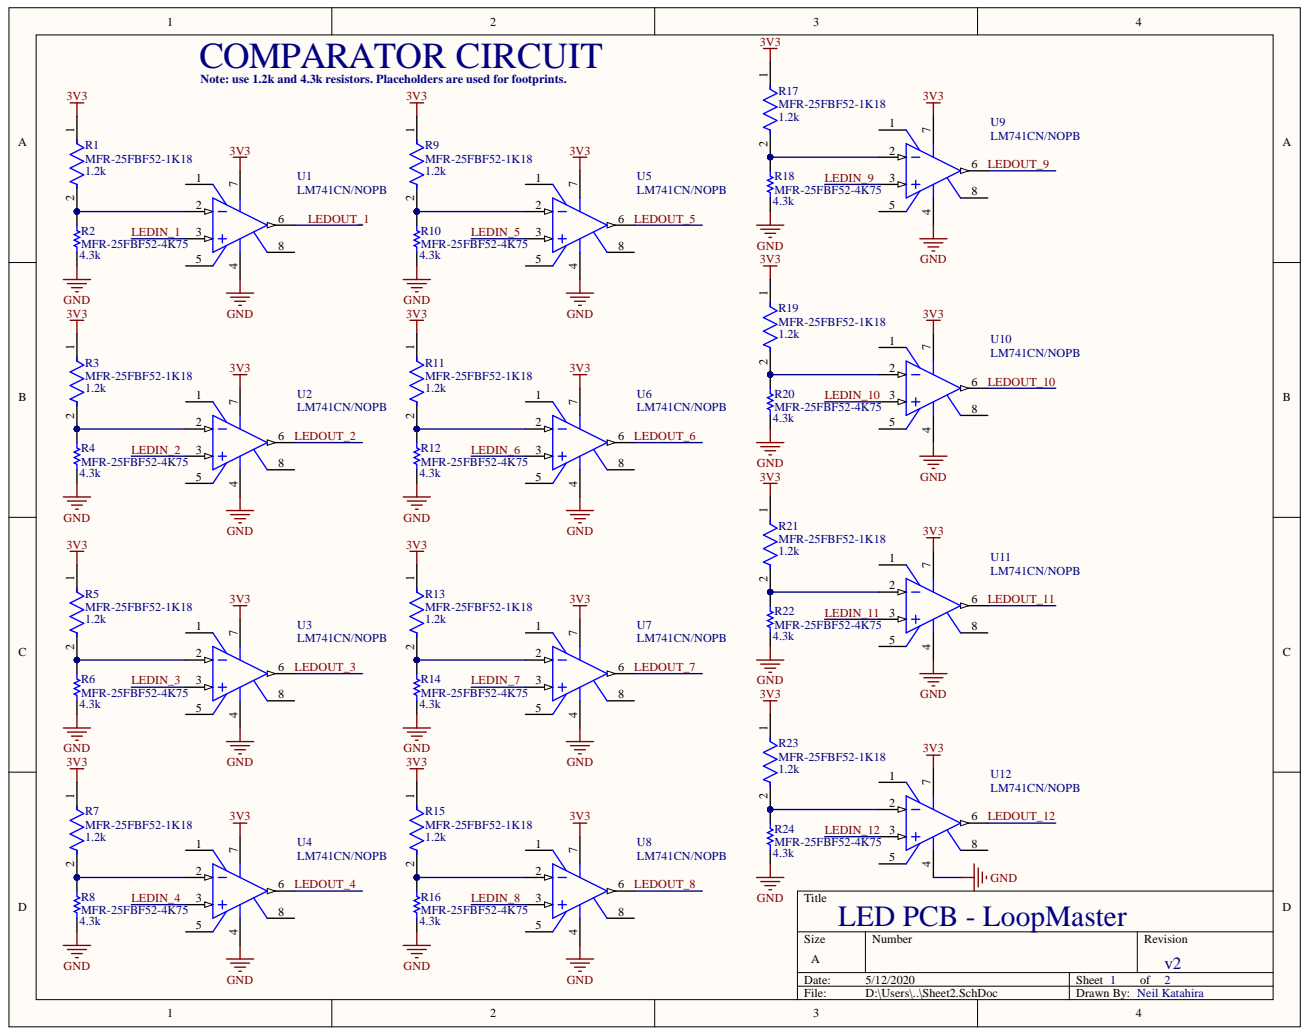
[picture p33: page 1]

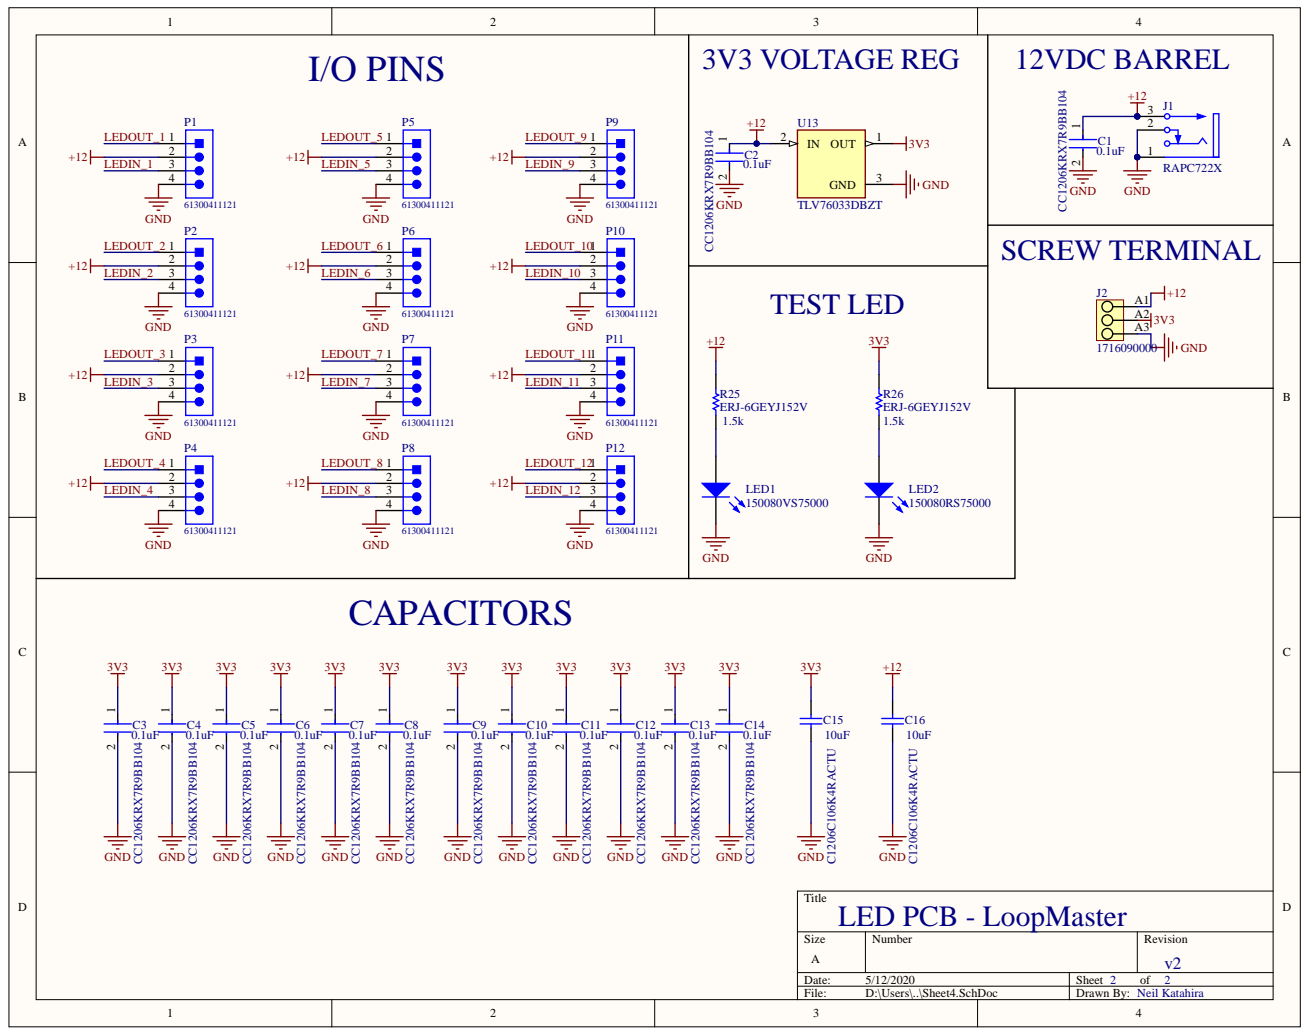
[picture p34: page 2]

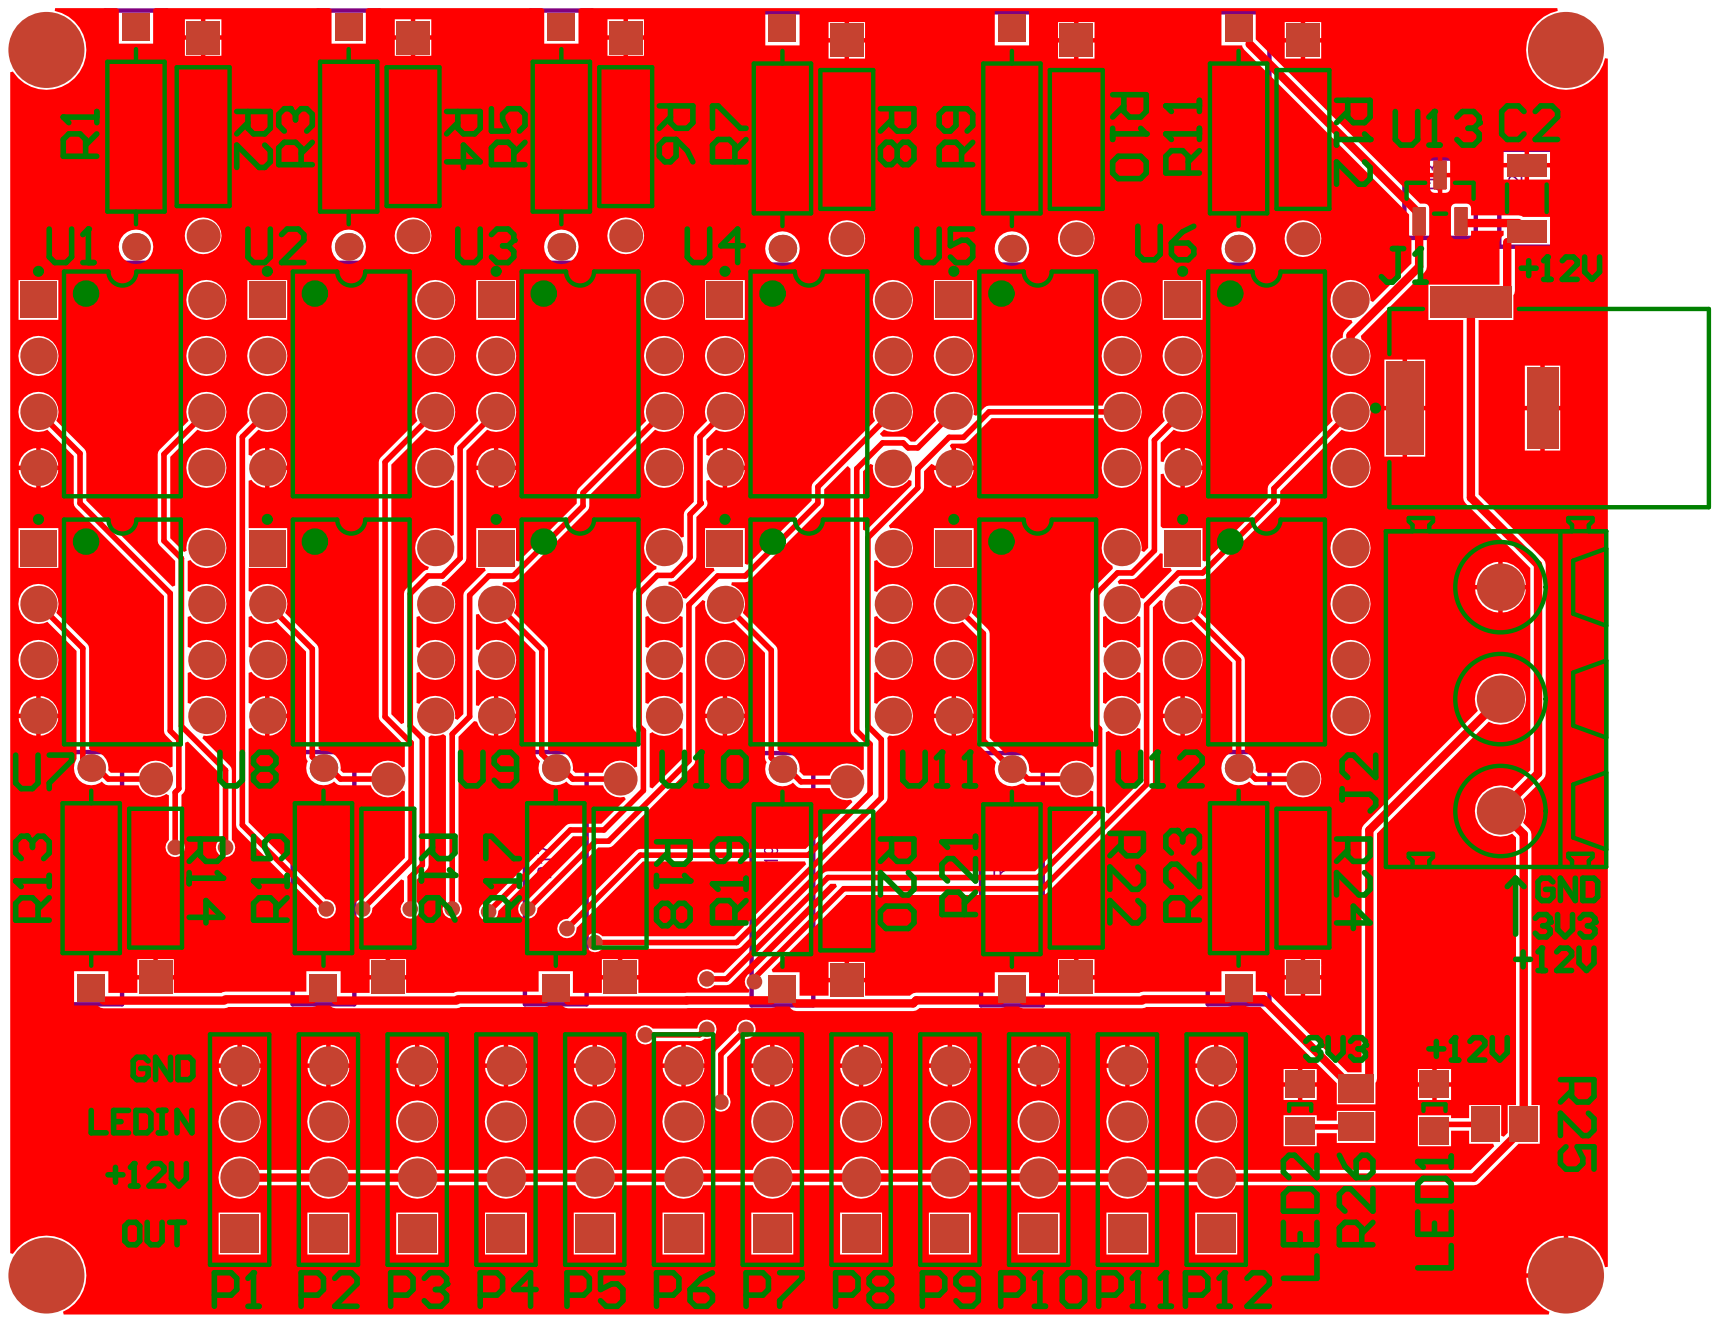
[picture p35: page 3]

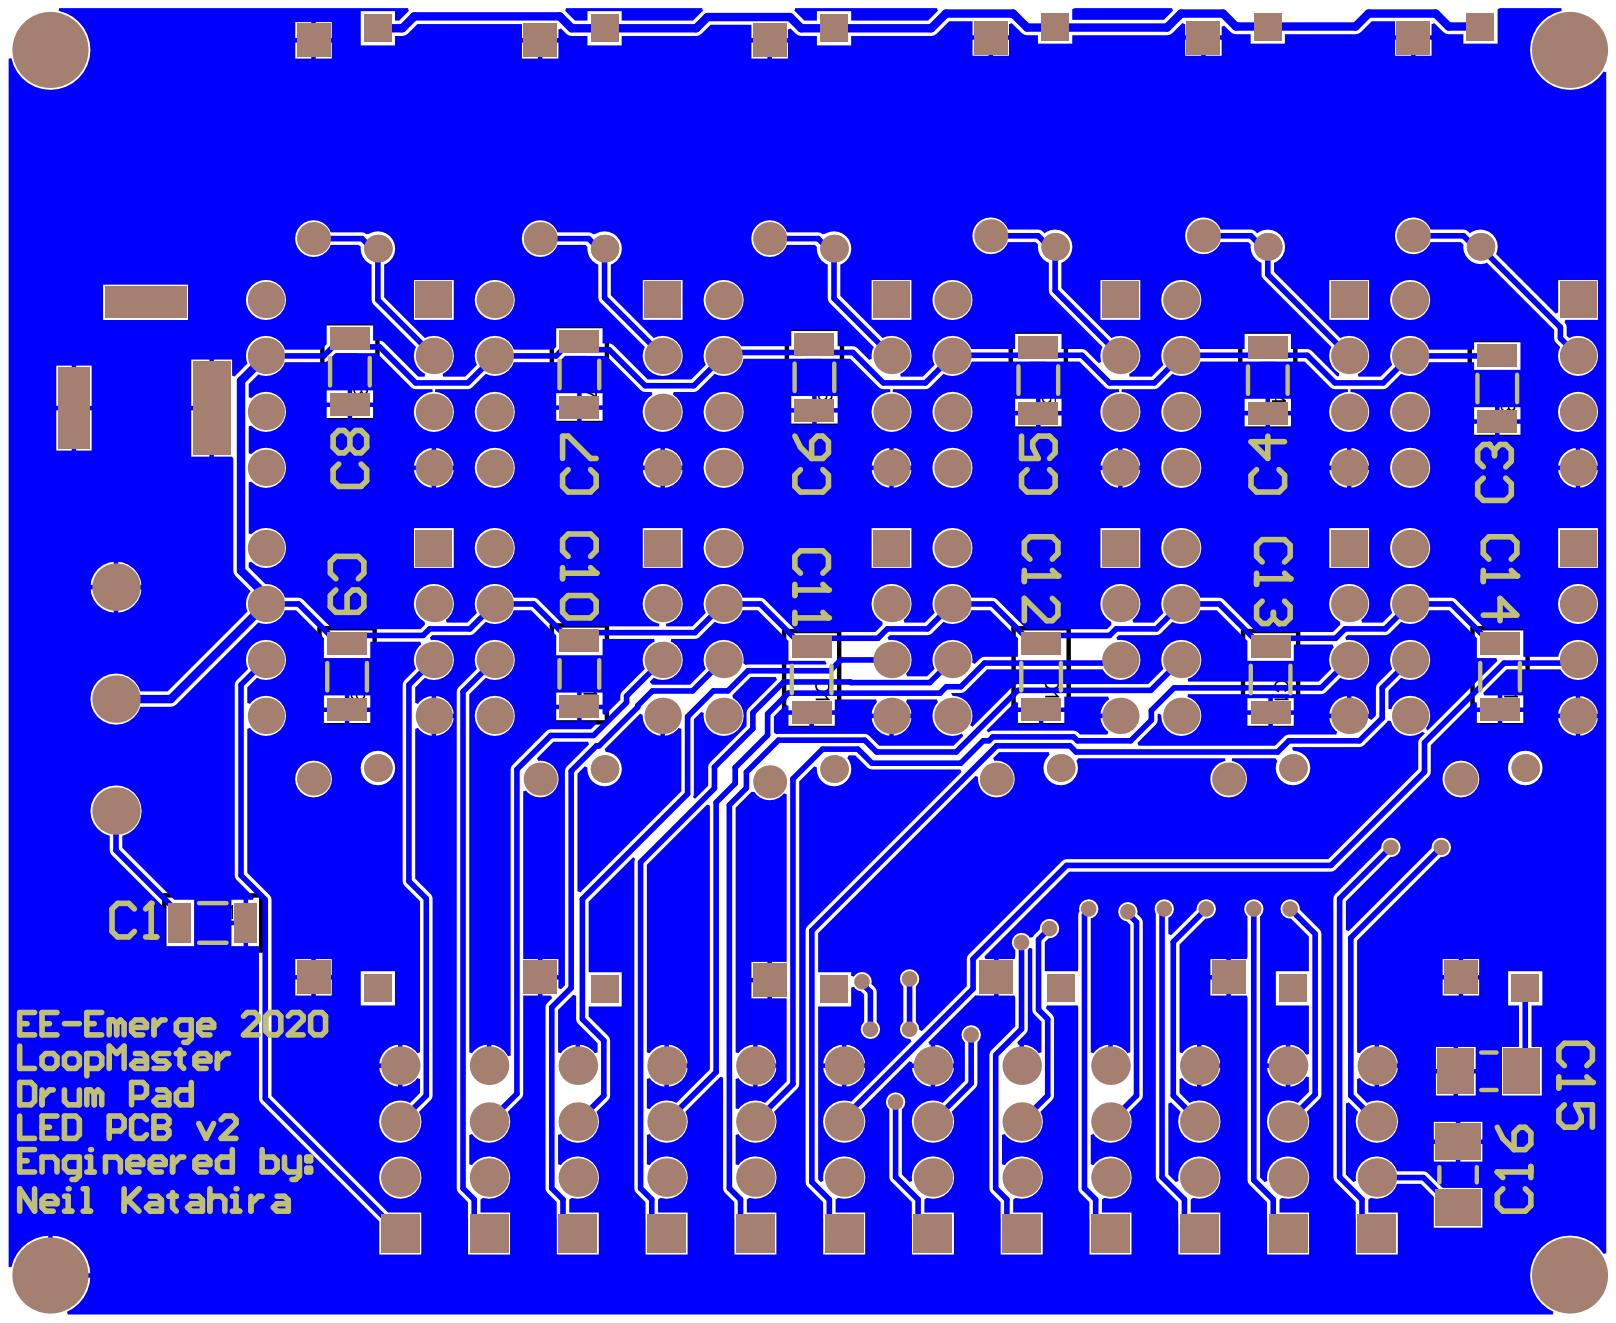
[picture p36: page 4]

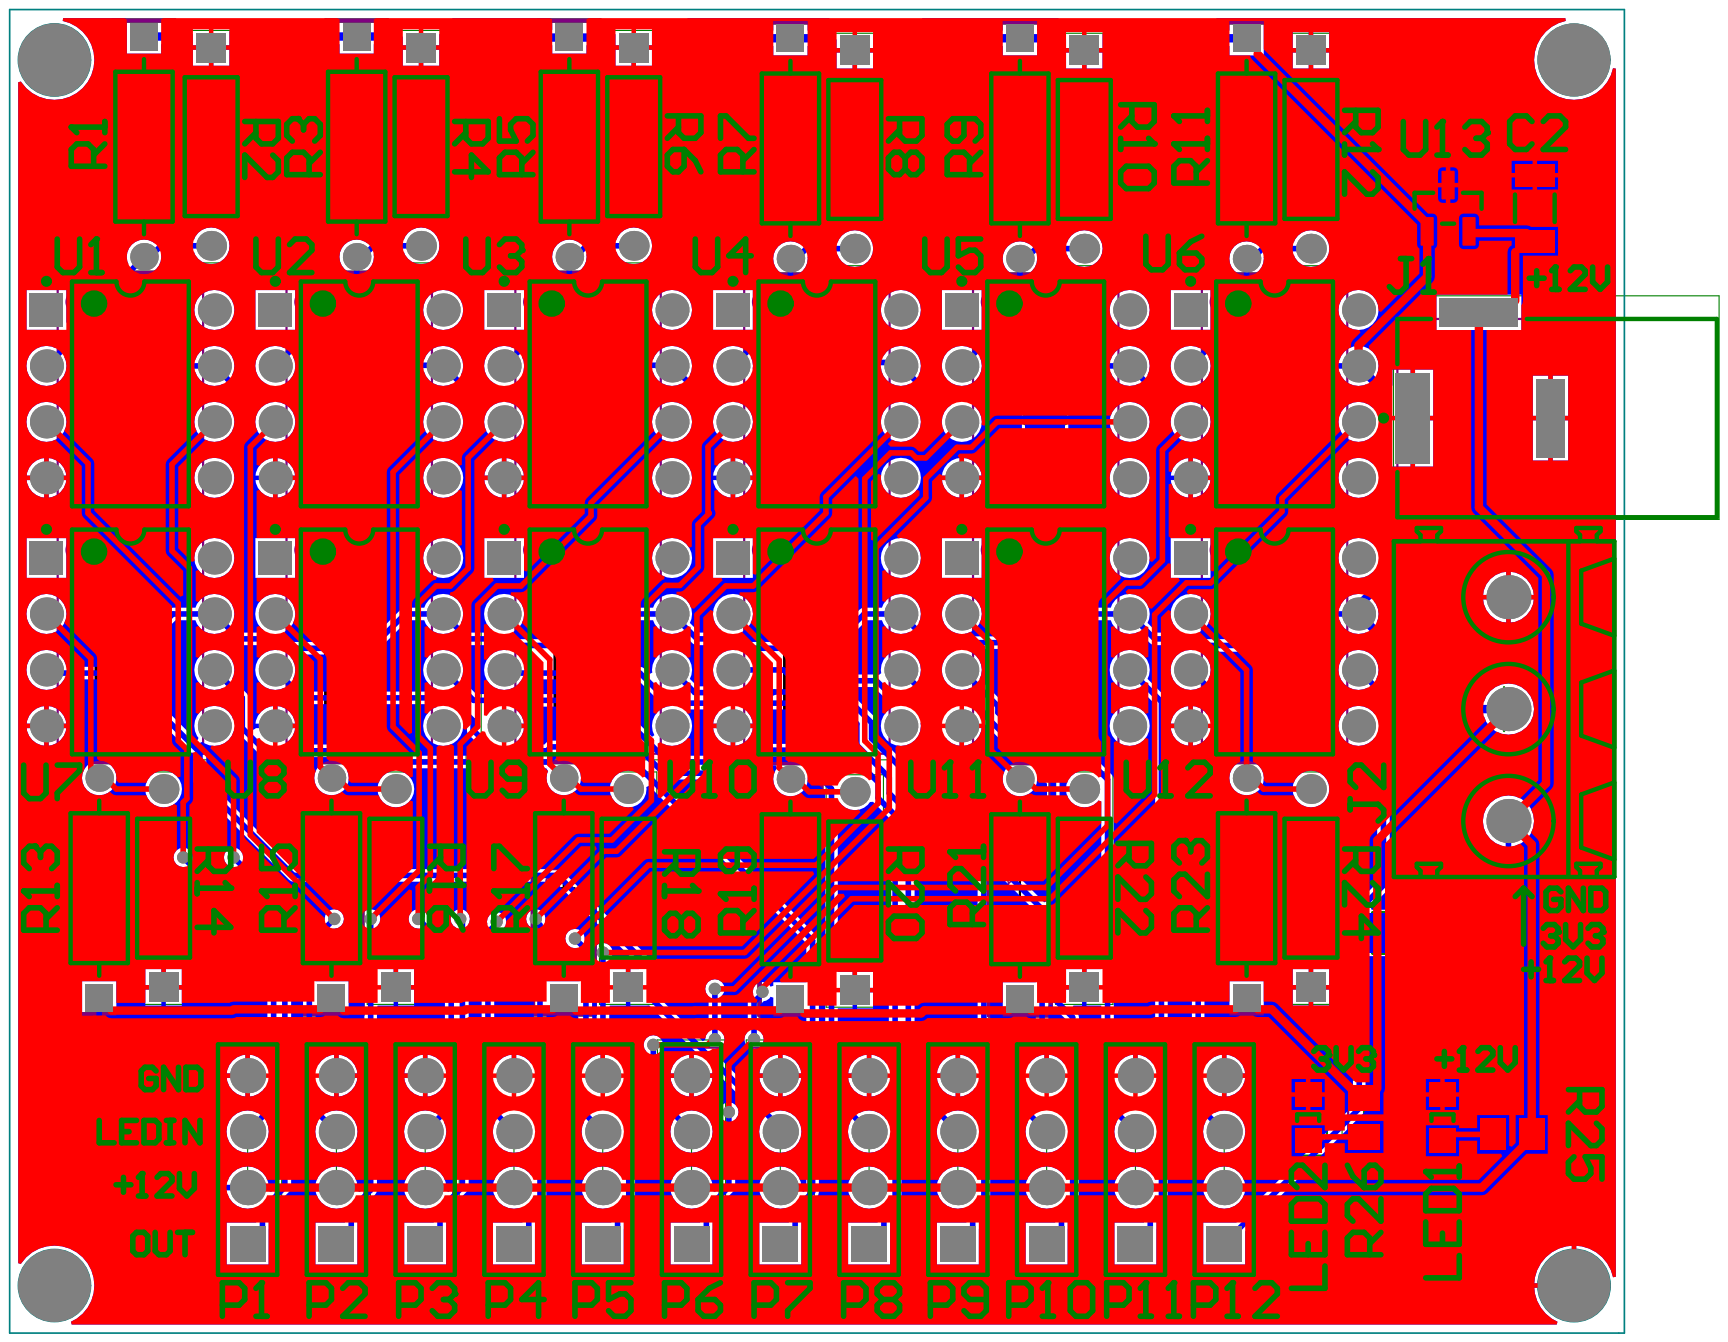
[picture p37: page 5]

Comment | Description | Designator | Footprint | LibRef | Quantity
CC1206KRX7R9BB104CAP CER 0.1UF 50V X7C1,C2,C3, C4, C5, C6FP-CC1206-1 _25-MFGCMP-03 422-0 00842-1 | | | | | 14
C1206C106K4RACTU | CAP, Ceramic, 10 uF, C1 5,C16 | | CAPC3216X1 80X50MLCMP-1664-00006-1 | | 2
RAPC722X | Power Jack, 5 A, 3-PinJ1 | | SWITCH-RAPC712X-3CMP-2000-05384-1 | | 1
1716090000 | OMNIMATE Signal - seJ2 | | LM_5_08_90_03 | CMP-1559-01768-1 | 1
150080VS75000 | SMD mono-color ChipLED1 | | 0805_A | CMP-1426-00009-1 | 1
150080RS75000 | SMD mono-color Chip L2 | | 0805_A | CMP-1426-00011-1 | 1
61300411121 | THT Vertical Pin HeadeP 1, P2, P3,P4,P5,P661300411121 | | | CMP-1502-01064-1 | 12
MFR-25FBF52-1K18 | RES 1.18K OHM 1/4WR1, R3, R5, R7, R9, R1FP-MFR-25-MFG | | | CMP-03 413-000001-1 | 12
MFR-25FBF52-4K75 | Axial Resistor, 4.75 KOhR2, R4, R6, R8,R10, RRESA60-630X240 | | | CMP-165 9-00066-1 | 12
ERJ-6GEYJ152V | | R25,R26 | RESC2013X70X40NL2CMP-2001-00355-1 | | 2
LM741CN/NOPB | Operational Amplifier, 8U1,U2,U3,U4, U5, UP0 008A | | | CMP-0055-00162-3 | 12
TLV76033DBZT | IC REG LINEAR 3.3V 1U13 | | FP-DBZ0003A-MFG | CMP-04917-000033-1 | 1

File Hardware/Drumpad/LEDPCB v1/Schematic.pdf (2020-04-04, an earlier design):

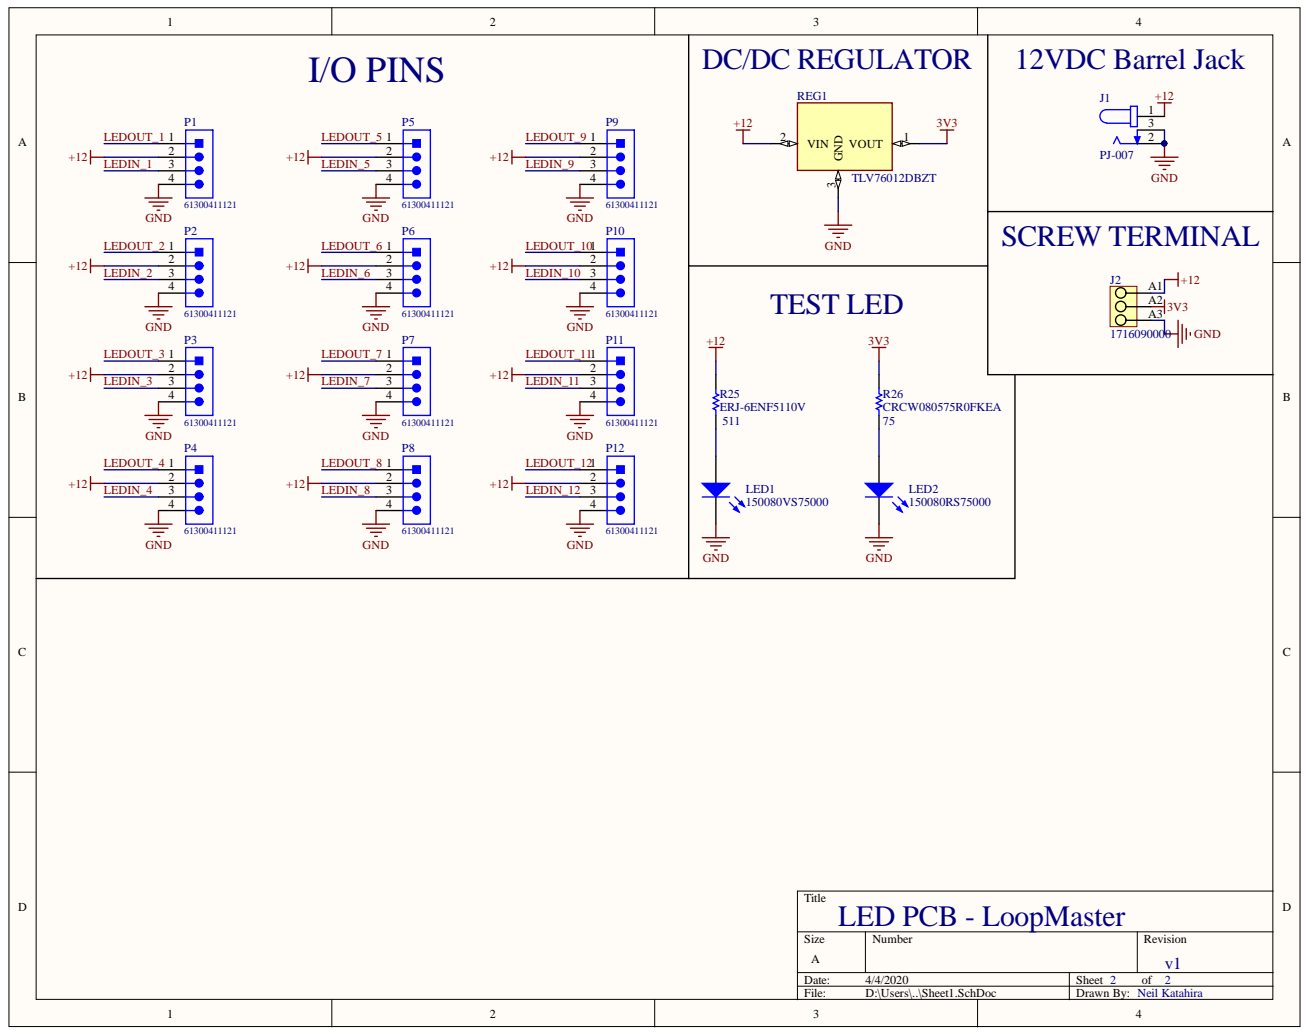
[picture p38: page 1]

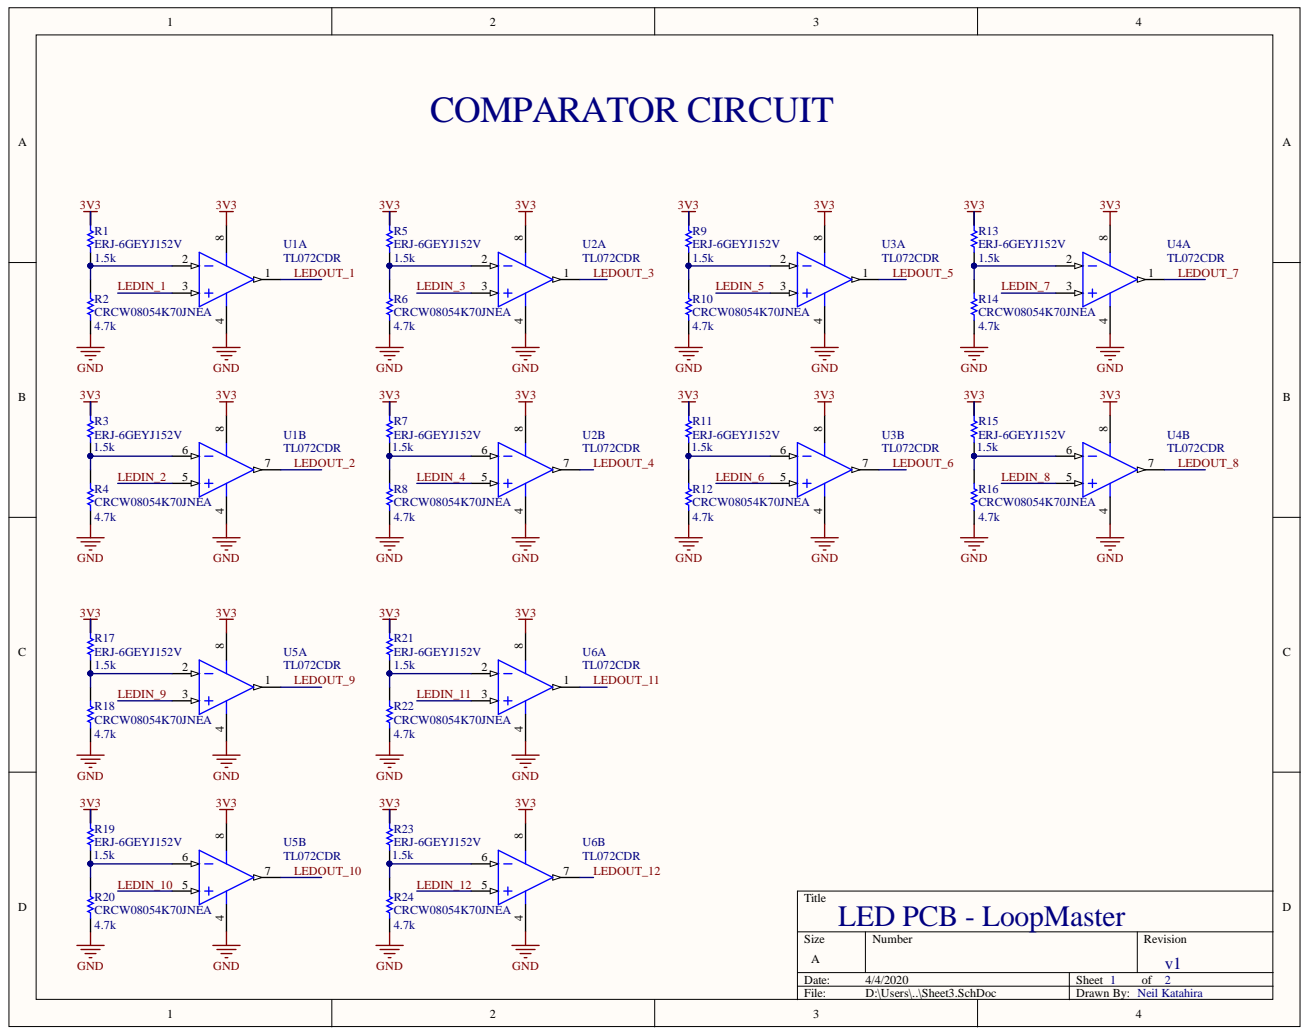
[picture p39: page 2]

# Board Stack Report

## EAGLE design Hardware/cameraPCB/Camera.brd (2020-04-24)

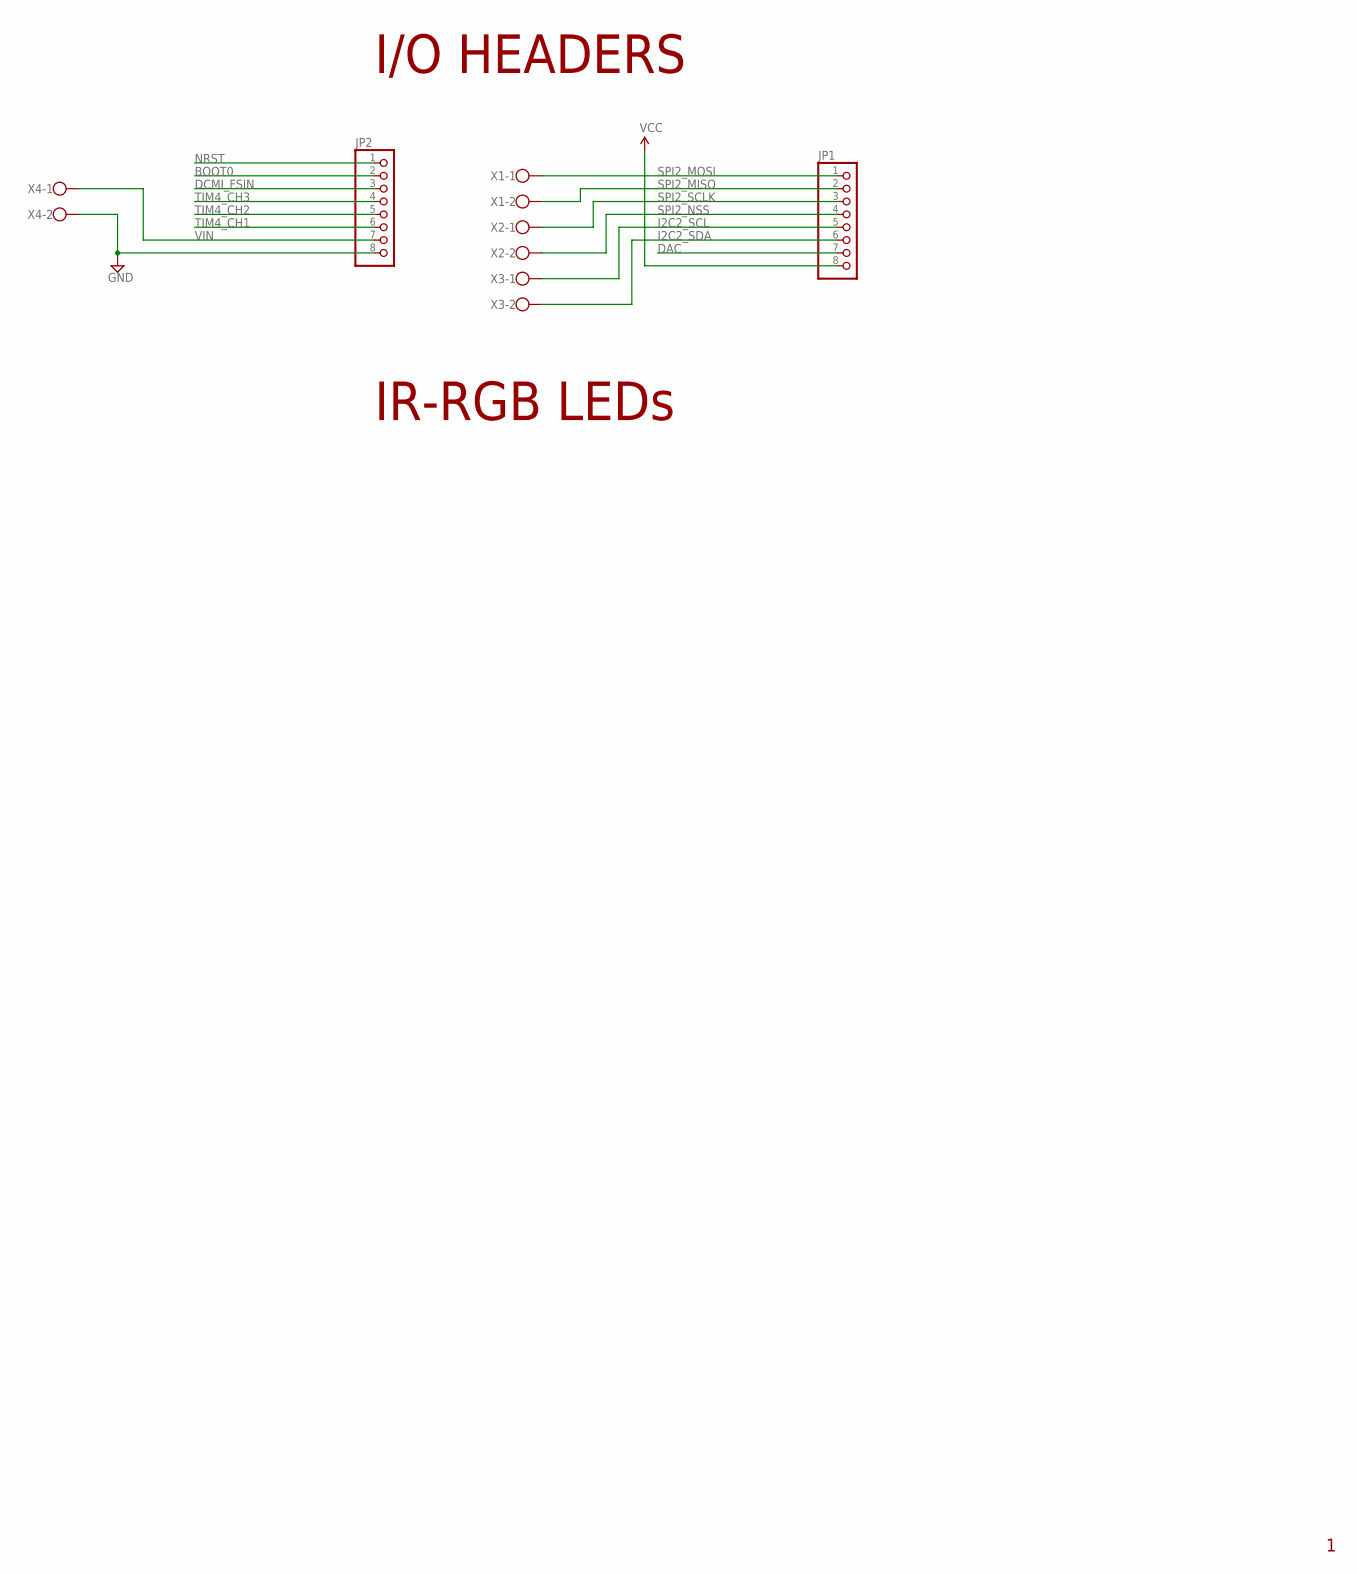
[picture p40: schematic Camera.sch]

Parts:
JP1, JP2: PINHD-1X8; 1X08
X1, X2, X3, X4: W237-102

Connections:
BOOT0: JP2.2
DAC: JP1.7
DCMI_FSIN: JP2.3
GND: JP2.8, X4.2
I2C2_SCL: JP1.5, X3.1
I2C2_SDA: JP1.6, X3.2
NRST: JP2.1
SPI2_MISO: JP1.2, X1.2
SPI2_MOSI: JP1.1, X1.1
SPI2_NSS: JP1.4, X2.2
SPI2_SCLK: JP1.3, X2.1
TIM4_CH1: JP2.6
TIM4_CH2: JP2.5
TIM4_CH3: JP2.4
VCC: JP1.8
VIN: JP2.7, X4.1

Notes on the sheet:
IR-RGB LEDs
I/O HEADERS

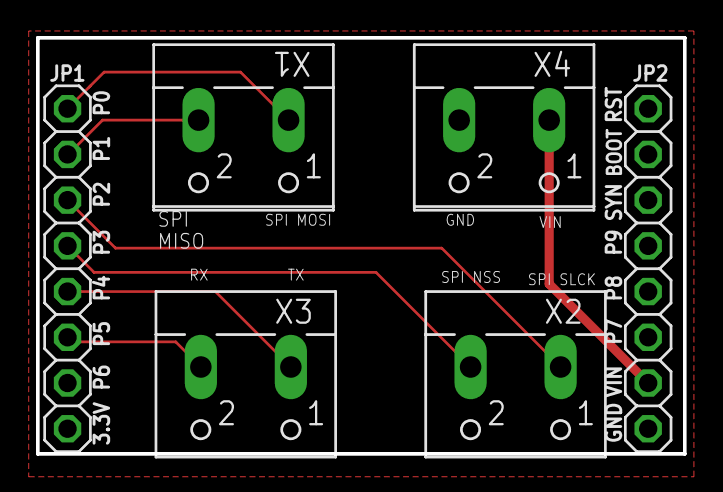
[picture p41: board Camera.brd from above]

Board: 2 copper layers, 35.9 x 23.1 mm, 6 parts (0 on the bottom side), 8 nets.

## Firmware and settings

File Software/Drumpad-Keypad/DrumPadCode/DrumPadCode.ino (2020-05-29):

int pressed = 0;
int flag1_4 = 0,
flag1_0 = 0,
flag1_3 = 0,
flag1_6 = 0,
flag1_5 = 0,
flag1_7 = 0,
flag2_0 = 0,
flag2_1 = 0,
flag2_4 = 0,
flag2_5 = 0,
flag2_6 = 0,
flag2_7 = 0;

int pin1_6state = 0,
pin1_4state = 0,
pin1_5state = 0,
pin1_7state = 0,
pin2_0state = 0,
pin2_1state = 0,
pin1_0state = 0,
pin1_3state = 0,
pin2_4state = 0,
pin2_5state = 0,
pin2_6state = 0,
pin2_7state = 0;

void setup()
{ 
  Serial.begin(115200);
  pinMode(P1_6, INPUT);
  pinMode(P1_4, INPUT);
 pinMode(P1_5, INPUT);
 pinMode(P1_7, INPUT);
 pinMode(P2_0, INPUT);
 pinMode(P2_1, INPUT);
 pinMode(P1_0, INPUT);
 pinMode(P1_3, INPUT);
 pinMode(P2_4, INPUT);
 pinMode(P2_5, INPUT);
 pinMode(P2_6, INPUT);
 pinMode(P2_7, INPUT);
//   attachInterrupt(digitalPinToInterrupt(P1_6),pressed1_6,RISING);
//   attachInterrupt(digitalPinToInterrupt(P1_4),pressed1_4,RISING); 
//   attachInterrupt(digitalPinToInterrupt(P1_6),released1_6,FALLING);
//   attachInterrupt(digitalPinToInterrupt(P1_4),released1_4,FALLING);  
}
void loop()
{
    pin1_6state = digitalRead(P1_6);
    pin1_4state = digitalRead(P1_4);
    
    pin1_5state = digitalRead(P1_5);
    pin1_7state = digitalRead(P1_7);
    pin2_0state = digitalRead(P2_0);
    pin2_1state = digitalRead(P2_1);
    pin1_0state = digitalRead(P1_0);
    pin1_3state = digitalRead(P1_3);
    pin2_4state = digitalRead(P2_4);
    pin2_5state = digitalRead(P2_5);
    pin2_6state = digitalRead(P2_6);
    pin2_7state = digitalRead(P2_7);

    if (pin1_6state > flag1_6)
      {
          Serial.write("A");
          flag1_6 = 1;
      }
    else if (pin1_6state < flag1_6)
      {
          Serial.write("|");
          flag1_6 = 0;
      }
    
    if (pin1_4state > flag1_4)
      {
          Serial.write("B");
          flag1_4 = 1;
      }
    else if(pin1_4state < flag1_4)
      {
          Serial.write("|");
          flag1_4 = 0;
      }
      
    if (pin1_5state > flag1_5)
     {
         Serial.write("C");
         flag1_5 = 1;
     }
    else if (pin1_5state < flag1_5)
     {
         Serial.write("|");
         flag1_5 = 0;
     }
    if (pin1_7state > flag1_7)
     {
         Serial.write("D");
         flag1_7 = 1;
     }
    else if (pin1_7state < flag1_7)
     {
         Serial.write("|");
         flag1_7 = 0;
     }
    if (pin2_0state > flag2_0)
     {
         Serial.write("E");
         flag2_0 = 1;
     }
    else if (pin2_0state < flag2_0)
     {
         Serial.write("|");
         flag2_0 = 0;
     }
    if (pin2_1state > flag2_1)
     {
         Serial.write("F");
         flag2_1 = 1;
     }
    else if (pin2_1state < flag2_1)
     {
         Serial.write("|");
         flag2_1 = 0;
     }
    if (pin1_0state > flag1_0)
     {
         Serial.write("G");
         flag1_0 = 1;
     }
    else if (pin1_0state < flag1_0)
     {
         Serial.write("|");
         flag1_0 = 0;
     }
    if (pin1_3state > flag1_3)
     {
         Serial.write("H");
         flag1_3 = 1;
     }
    else if (pin1_3state < flag1_3)
     {
         Serial.write("|");
         flag1_3 = 0;
     }
    if (pin2_4state > flag2_4)
     {
         Serial.write("I");
         flag2_4 = 1;
     }
    else if (pin2_4state < flag2_4)
     {
         Serial.write("|");
         flag2_4 = 0;
     }
    if (pin2_5state> flag2_5)
     {
         Serial.write("J");
         flag2_5 = 1;
     }
    else if (pin2_5state < flag2_5)
     {
         Serial.write("|");
         flag2_5 = 0;
     }
    if (pin2_6state> flag2_6)
     {
         Serial.write("K");
         flag2_6 = 1;
     }
    else if (pin2_6state < flag2_6)
     {
         Serial.write("|");
         flag2_6 = 0;
     }
    if (pin2_7state > flag2_7)
     {
         Serial.write("L");
         flag2_7 = 1;
     }
    else if (pin2_7state < flag2_7)
     {
         Serial.write("|");
         flag2_7 = 0;
     }
      delay (10);    
}
//void pressed1_6()
//{
//  Serial.write("A");
//  pressed = 1;
//}
//void pressed1_4()
//{
//  Serial.write("B");
//}
//
//void released1_6 ()
//{
//  Serial.write("|");
//}
//void released1_4 ()
//{
//  Serial.write("|");
//}
//

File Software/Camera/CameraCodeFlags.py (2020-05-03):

# Untitled - By: cdrow - Tue Feb 4 2020
#Single Color Grayscale Blob Tracking Example
#
# This example shows off single color grayscale tracking using the OpenMV Cam.

import sensor, image, time, pyb
from pyb import UART

# Color Tracking Thresholds (Grayscale Min, Grayscale Max)
# The below grayscale threshold is set to only find extremely bright white areas.
thresholds = (253, 255)
uart = UART(3,115200,timeout_char=1000)
uart.init(115200, bits=8, parity=None, stop=1, timeout_char=1000)

sensor.reset()
sensor.set_pixformat(sensor.GRAYSCALE)
sensor.set_framesize(sensor.QQVGA)
sensor.skip_frames(time = 2000)
sensor.set_auto_gain(False) # must be turned off for color tracking
sensor.set_auto_whitebal(False) # must be turned off for color tracking
clock = time.clock()
chordold = "0";
# lcd.init() # Initialize the lcd screen.

# Only blobs that with more pixels than "pixel_threshold" and more area than "area_threshold" are
# returned by "find_blobs" below. Change "pixels_threshold" and "area_threshold" if you change the
# camera resolution. "merge=True" merges all overlapping blobs in the image.

while(True):
   clock.tick()
   img = sensor.snapshot()
   chord = "0"
   for blob in img.find_blobs([thresholds], pixels_threshold=10, area_threshold=10, merge=True):
       img.draw_rectangle(blob.rect())
       img.draw_cross(blob.cx(), blob.cy())
       #all this code above just draws the outline of what it find, for troubleshooting
       # split the screen into 5 regions
       if ((blob.cx() <= 45) and (blob.cy() <= 45)):
           img.draw_rectangle(0,0,45,45,(255,0,0))
           chord = "1"
           #print("1")
       if ((blob.cx() <= 45) and (blob.cy() >= 120-45)):
           img.draw_rectangle(0,120-45,45,45,(255,0,0))
           chord = "4"
           #print("4")
       if (blob.cx() >= 128 and blob.cy() <= 32):
           img.draw_rectangle(160-45,0,45,45,(255,0,0))
           chord = "2"
           #print("2")
       if (blob.cx() >= 128 and blob.cy() >= 88):
           img.draw_rectangle(160-45,120-45,45,45,(255,0,0))
           chord = "3"
           #print("3")
       #if ((blob.cx() >= 64 and blob.cx() <= 96) and (blob.cy() >= 45 and blob.cy() <= 77)):
           #img.draw_rectangle(64,45,45,45,(255,0,0))
          #chord = "5"
       if (chordold != chord):
           uart.write(chord)
           print(chord)
       chordold = chord;

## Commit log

2020-01-17 Update OpenmvCode.py
    Removed SPI Code because we are going toward UART
2020-01-24 working uart
2020-01-31 Arduino Uno SPI initialization
2020-04-04 Reorganization
    Reorganization and hardware/mechanical file additions
    [CUI_PJ-007.PcbLib, Drumpad Base + Walls.stl, Drumpad Top.stl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]
2020-04-19 Create drumpad pcb plate v2.stl
    [drumpad pcb plate v2.stl]
2020-04-24 Update website readme and drumpad stl
    [Drumpad Base + Walls.stl]
2020-04-26 MATLAB GUI & corresponding Arduino files
2020-04-28 Screw hole size changes
    [Drumpad Base + Walls.stl, Drumpad Top.stl]
2020-04-28 Increased standoff sizes + fixed cable hole
    [Drumpad Base + Walls.stl]
2020-04-29 Added supports for mounting holes
    [Drumpad Base + Walls.stl]
2020-05-12 Drumpad LED PCB v2
    New revision of the Drumpad LED PCB. Includes Altium files, gerbers, pictures and schematic PDF.
    [CUI_PJ-007.PcbLib, LEDPCB.SchLib, PCB1.PcbDoc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]
2020-05-12 Folder name change
    [PCB1.PcbDoc, PCB_Project.PrjPcb, Sheet2.SchDoc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]
2020-05-12 Update for LEDPCB v2
    [Drumpad Base + Walls.stl]
2020-05-12 Reoriented standoffs for LED PCB, resized hole sizes for mainboard
    [Drumpad Base + Walls.stl, Drumpad Top.stl]
2020-05-15 Changed screw size for mainboard
    Screw size of mainboard from M2 to M2.5
    [Drumpad Base + Walls.stl]
2020-05-21 Update Drumpad Base + Walls.stl
    [Drumpad Base + Walls.stl]
2020-05-23 replaced with the folder
    [DrumPadCode.ino]
2020-05-23 Create Name v2.stl
    [Name v2.stl]
2020-05-24 Camera vision to computer
2020-05-24 Removed Xbee board standoffs
    [Drumpad Base + Walls.stl]
2020-05-29 camera vision
2020-05-29 Update and rename computervision.md to camera.md
